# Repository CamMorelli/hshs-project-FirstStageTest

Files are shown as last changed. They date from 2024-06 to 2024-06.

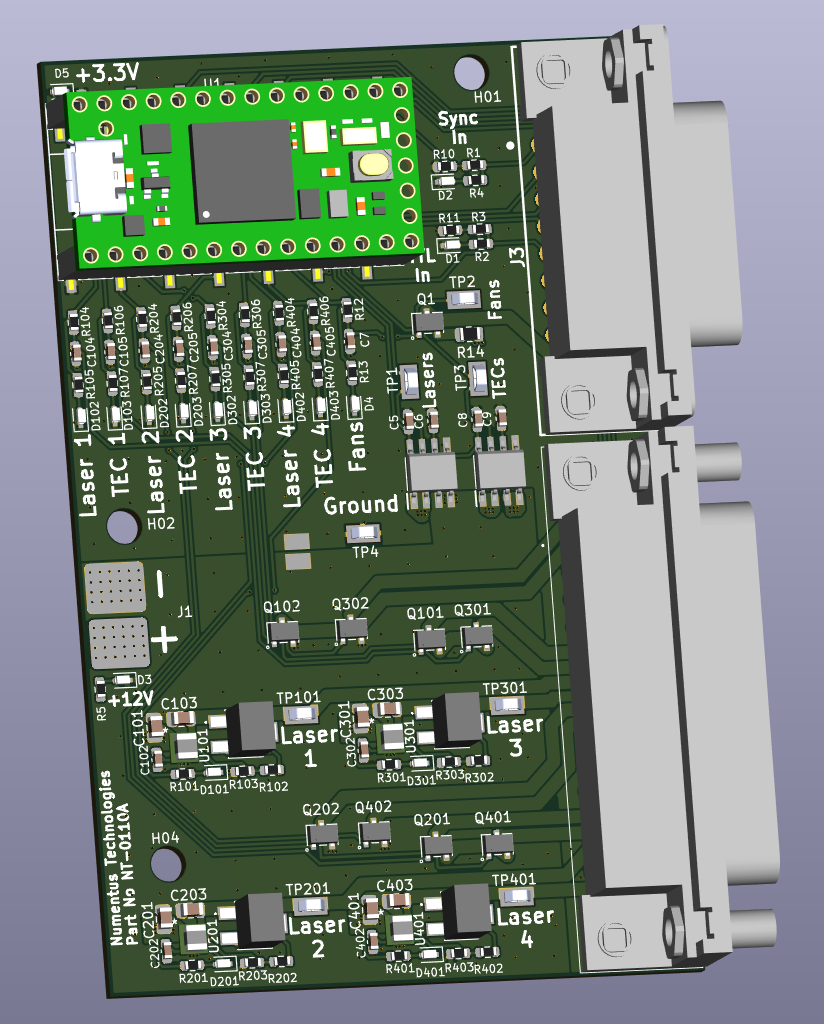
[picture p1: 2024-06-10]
Hardware/HSHS Interface Board 0110B/Assembly Documents/Screen Shot 2024-04-10 at 11.27.20 AM.png

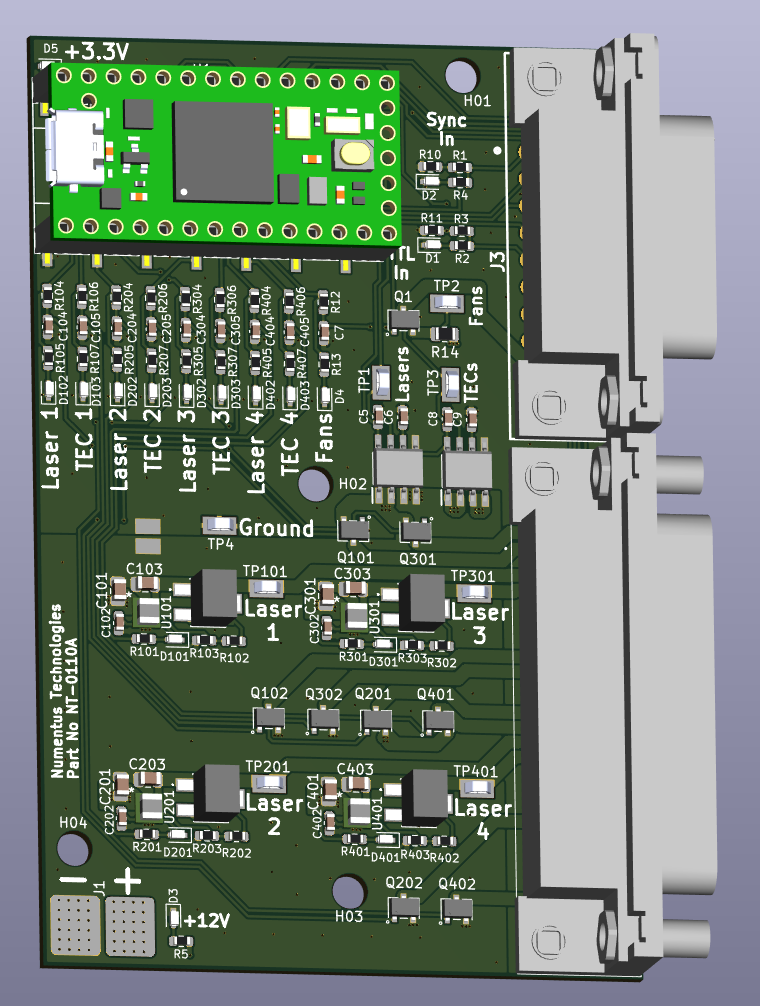
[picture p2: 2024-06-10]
Hardware/HSHS Interface Board 0110A/Assembly Documents/Screen Shot 2024-03-24 at 6.15.04 PM.png

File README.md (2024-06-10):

# crisp teensy project

## Getting started

To make it easy for you to get started with GitLab, here's a list of recommended next steps.

Already a pro? Just edit this README.md and make it your own. Want to make it easy? [Use the template at the bottom](#editing-this-readme)!

## Add your files

- [ ] [Create](https://docs.gitlab.com/ee/user/project/repository/web_editor.html#create-a-file) or [upload](https://docs.gitlab.com/ee/user/project/repository/web_editor.html#upload-a-file) files
- [ ] [Add files using the command line](https://docs.gitlab.com/ee/gitlab-basics/add-file.html#add-a-file-using-the-command-line) or push an existing Git repository with the following command:

```
cd existing_repo
git remote add origin https://gitlab.com/numentus-technologies/crisp-teensy-project.git
git branch -M main
git push -uf origin main
```

## Integrate with your tools

- [ ] [Set up project integrations](https://gitlab.com/numentus-technologies/crisp-teensy-project/-/settings/integrations)

## Collaborate with your team

- [ ] [Invite team members and collaborators](https://docs.gitlab.com/ee/user/project/members/)
- [ ] [Create a new merge request](https://docs.gitlab.com/ee/user/project/merge_requests/creating_merge_requests.html)
- [ ] [Automatically close issues from merge requests](https://docs.gitlab.com/ee/user/project/issues/managing_issues.html#closing-issues-automatically)
- [ ] [Enable merge request approvals](https://docs.gitlab.com/ee/user/project/merge_requests/approvals/)
- [ ] [Set auto-merge](https://docs.gitlab.com/ee/user/project/merge_requests/merge_when_pipeline_succeeds.html)

## Test and Deploy

Use the built-in continuous integration in GitLab.

- [ ] [Get started with GitLab CI/CD](https://docs.gitlab.com/ee/ci/quick_start/index.html)
- [ ] [Analyze your code for known vulnerabilities with Static Application Security Testing(SAST)](https://docs.gitlab.com/ee/user/application_security/sast/)
- [ ] [Deploy to Kubernetes, Amazon EC2, or Amazon ECS using Auto Deploy](https://docs.gitlab.com/ee/topics/autodevops/requirements.html)
- [ ] [Use pull-based deployments for improved Kubernetes management](https://docs.gitlab.com/ee/user/clusters/agent/)
- [ ] [Set up protected environments](https://docs.gitlab.com/ee/ci/environments/protected_environments.html)

***

# Editing this README

When you're ready to make this README your own, just edit this file and use the handy template below (or feel free to structure it however you want - this is just a starting point!). Thank you to [makeareadme.com](https://www.makeareadme.com/) for this template.

## Suggestions for a good README
Every project is different, so consider which of these sections apply to yours. The sections used in the template are suggestions for most open source projects. Also keep in mind that while a README can be too long and detailed, too long is better than too short. If you think your README is too long, consider utilizing another form of documentation rather than cutting out information.

## Name
Teensy interface for ASI Imaging CRISP autofocus module

## Description
Let people know what your project can do specifically. Provide context and add a link to any reference visitors might be unfamiliar with. A list of Features or a Background subsection can also be added here. If there are alternatives to your project, this is a good place to list differentiating factors.

## Badges
On some READMEs, you may see small images that convey metadata, such as whether or not all the tests are passing for the project. You can use Shields to add some to your README. Many services also have instructions for adding a badge.

## Visuals
Depending on what you are making, it can be a good idea to include screenshots or even a video (you'll frequently see GIFs rather than actual videos). Tools like ttygif can help, but check out Asciinema for a more sophisticated method.

## Installation
Within a particular ecosystem, there may be a common way of installing things, such as using Yarn, NuGet, or Homebrew. However, consider the possibility that whoever is reading your README is a novice and would like more guidance. Listing specific steps helps remove ambiguity and gets people to using your project as quickly as possible. If it only runs in a specific context like a particular programming language version or operating system or has dependencies that have to be installed manually, also add a Requirements subsection.

## Usage
Use examples liberally, and show the expected output if you can. It's helpful to have inline the smallest example of usage that you can demonstrate, while providing links to more sophisticated examples if they are too long to reasonably include in the README.

## Support
Tell people where they can go to for help. It can be any combination of an issue tracker, a chat room, an email address, etc.

## Roadmap
If you have ideas for releases in the future, it is a good idea to list them in the README.

## Contributing
State if you are open to contributions and what your requirements are for accepting them.

For people who want to make changes to your project, it's helpful to have some documentation on how to get started. Perhaps there is a script that they should run or some environment variables that they need to set. Make these steps explicit. These instructions could also be useful to your future self.

You can also document commands to lint the code or run tests. These steps help to ensure high code quality and reduce the likelihood that the changes inadvertently break something. Having instructions for running tests is especially helpful if it requires external setup, such as starting a Selenium server for testing in a browser.

## Authors and acknowledgment
Show your appreciation to those who have contributed to the project.

## License
For open source projects, say how it is licensed.

## Project status
If you have run out of energy or time for your project, put a note at the top of the README saying that development has slowed down or stopped completely. Someone may choose to fork your project or volunteer to step in as a maintainer or owner, allowing your project to keep going. You can also make an explicit request for maintainers.

# Cameron: These are my personal setups for VS Code and C++ thus far for documentation purposes.

# For the setup of VS Code, so far I have installed the following extensions:
Python
C/C++
C/C++ Extension Pack
C/C++ Themes
CMake
Cmake Tools
Doxygen Documentation Generator
Git Graph
GitLab Workflow
PlatformIO IDE
Pylance
Pylint
Python Debugger

# I then installed the following modules via pip using the command "pip install (module)":
numpy
matplotlib
pyserial **NOTE: for the import command to access pyserial, the command is as follows: "import serial" NOT "import pyserial"**

# For the setup of GitLab and GitHub, I signed into my Git account, and linked it to VS Code through the GitLab Workflow extension.
This allowed me to save my changes as my account and properly document it under GitGraph when a change is requested.
I then accessed the specific online (not local) repository via email granted access from the authorized user.
I continue to access the HSHS project via GitLab's website. (To first log in there will be a free trial button, of which, if you press, will being you to a sign in button in order to access your preexisting account)

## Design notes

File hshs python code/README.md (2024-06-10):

# Teensy CRISP python

## Name
Teensy CRISP python

## Known Bugs

## Testing
Tested on Python 3.10

## Description
<!-- Let people know what your project can do specifically. Provide context and add a link to any reference visitors might be unfamiliar with. A list of Features or a Background subsection can also be added here. If there are alternatives to your project, this is a good place to list differentiating factors. -->

Handling widget events:
The program responds to both shortcut keys and clicking widgets. The supporting code is primarily in hshs_gui_interface
Shortcut keys (in key_list) are bound to the function handle_global_key_press, which then calls functions by key
Clicking widgets results in function calls, set up during creation using "command = "
<KeyRelease> is bound to function handle_entry_key_press as follows:
For 'Up' and 'Down' arrows, current value (text) is tested for validity for arrow changes, then increamented/decremented based on cursor position
'Return' or 'KP_Enter' call focus to the main controller (focus out for the widget); tab also generates a focus out withut this step
<FocusOut> is bound to handle_focus_out, which also updates widgets and calls functions
Both 'Up' and 'Down' (handle_entry_key_press, but no FocusOut) and <FocusOut> update widgets through:
(1) update_param method for EntryParam Class: does validity check, then updates stored variable and widget display
(2) calls to update_plot_limits (axis values) or update_mcu (microcontroller values) to make changes 

To add to GUI:
    Add frame for GUI elements in pcr_controller_new_start in Class init for proper page (Settings, Data, or Fits)
    create method to populate widgets (e.g., roi_centers_controls_widgets, pwm_controls_widgets
    Call method from main program (pcr_controller_new_start)
    Define value, default value, max, min, etc for each widget
    Each element will reference the frame from first step
    Include list of widgets for (1) inclusion of current values in config.json file and (2) loop creation such as by gui_obj.create_widgets or gui_obj.create_buttons
    Add above list to json_obj_list

To add states:
    Edit state_control.hpp and hshs_constants.py to add new state to stateType and STATE_LIST and PLOT_TYPE, respectively
    Add state button in self.button_type in mcu_comm, and 
    Add state shortcut to key_list in hshs_controller and handle_mcu_command in mcu_comm
    Edit serial_comm.cpp to add relevant commands to help list and command call to processInputLine
    Edit process.hpp and process.cpp to add function to handle command
    Edit state_control.hpp to handle appropriate case(s) in updateState

## Files
hshs_controller_new-start.py: Starts up program, handling the creation and eventual destruction of Tkinter GUI
hshs_mcu_comm.py: Handles reading and writing from port (read from port thread) as well as interaction between user and GUI
hshs_plot_class.py: Handles details of displaying images and other data on GUI
hshs_gui_interface.py: Basic functionality of interacting with GUI like creating buttons and handling key presses
hshs_file_save.py: Handle file save thread, saving data to files
hshs_constants.py: Center for constants to be used in dimenions of GUI

## Visuals
<!-- Depending on what you are making, it can be a good idea to include screenshots or even a video (you'll frequently see GIFs rather than actual videos). Tools like ttygif can help, but check out Asciinema for a more sophisticated method. -->

## Installation

You will need to install several modules (e.g. using pip) including: serial, pyserial

<!-- Within a particular ecosystem, there may be a common way of installing things, such as using Yarn, NuGet, or Homebrew. However, consider the possibility that whoever is reading your README is a novice and would like more guidance. Listing specific steps helps remove ambiguity and gets people to using your project as quickly as possible. If it only runs in a specific context like a particular programming language version or operating system or has dependencies that have to be installed manually, also add a Requirements subsection. -->

## Usage
<!-- Use examples liberally, and show the expected output if you can. It's helpful to have inline the smallest example of usage that you can demonstrate, while providing links to more sophisticated examples if they are too long to reasonably include in the README. -->

## Support
<!-- Tell people where they can go to for help. It can be any combination of an issue tracker, a chat room, an email address, etc. -->

## Roadmap
<!-- Ideas for the future. -->

Update command list, implement/repurpose commands, implement/repurpose return values

States: Lock, ready (no servo), manual servo, scan, off (LED off)

Commands: Lock, Ready, Manual, scan (limits, time), servo level (value), LED level (value), servo off, gain values
Error - servo at limit
Limit servo rate of change
Add PID/Lock

Outputs to MCU: state changes, live servo voltage, LED level
Returns from MCU: two photodiode signals, error signal, servo voltage, state

Consider what warnings/confirmations you want to pop up when the user tries to do something that is unavailable or risky.

Add an option for pausing collection.

To get more control over the placement of elements on the Data Page, one might consider breaking up the display frame into more rows and columns and just increasing the span of those large elements that are currently there.

Some reorganization across classes and files could make the code more digestible. pcr_mcu_comm.py is especially long
## Contributing
<!-- State if you are open to contributions and what your requirements are for accepting them.

For people who want to make changes to your project, it's helpful to have some documentation on how to get started. Perhaps there is a script that they should run or some environment variables that they need to set. Make these steps explicit. These instructions could also be useful to your future self.

You can also document commands to lint the code or run tests. These steps help to ensure high code quality and reduce the likelihood that the changes inadvertently break something. Having instructions for running tests is especially helpful if it requires external setup, such as starting a Selenium server for testing in a browser. -->

## Authors and acknowledgment
Gregory Faris

## License
<!-- For open source projects, say how it is licensed. -->

## Project status
<!-- If you have run out of energy or time for your project, put a note at the top of the README saying that development has slowed down or stopped completely. Someone may choose to fork your project or volunteer to step in as a maintainer or owner, allowing your project to keep going. You can also make an explicit request for maintainers. -->

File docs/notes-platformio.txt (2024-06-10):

(1) teensy
https://www.pjrc.com/store/teensy40.html#photos

download teensy loader on ubuntu and mac
https://www.pjrc.com/teensy/loader_linux.html
success

executed ./teensy
success

screen /dev/ttyACM0 115200  (linux)
screen /dev/ttyACM0 115200  (linux)

control-c / control-d
success

platformio tutorial
https://www.youtube.com/watch?v=k3tpNwXEWhU

platformio useful commands:
View/Command Palette -> PlatformIO: Rebuild Intellisense Index

platformio docs home:
https://docs.platformio.org/en/latest/core/index.html

cd teensy-a(b)
PATH=${PATH}:${HOME}/.platformio/penv/bin

pio lib search "id:89"
pio lib search "platform: Espressif 8266 AND keyword:mqtt"
pio lib search "platform: Espressif 8266 AND keyword:serial"
pio lib search "id:89 8266 AND keyword:mqtt"
pio lib search -n mqtt
pio settings get

There is no equivalent icon in VSCode for this command. If you want to do this in VSCode, click on "pio" folder from right side in Teensy A or teensy
B and then selecting delete
rm -rf .pio 

This is the same as the trash can
pio run --target clean

This is the same as the check icon
pio run -v

This is the same as the right arrow icon
pio run --target upload

This is the same as the power plug
pio device monitor

NOTE: WHEN IN TROUBLE and there are issues with common library (i.e., with  LineParsingResult, getToken, etc)  
or when editing lib from IDE and "trash can" doesn't clear prior pio build,
try right clicking ".pio" folder from right side in Teensy A or teensy
B and then selecting delete. This is OK and doesn't hurt anything as .pio will be restored during the next build

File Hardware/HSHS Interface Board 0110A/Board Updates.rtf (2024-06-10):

Board Updates
Add ground test point
Move Laser and TEC LED Indicators to outputs somehow???
Less current to indicator LEDs (more than 500 Ohms) (balance lumens?)
Use Hall sensors for current
Power supply to outside
Mounting holes
Update LED footprints (AA1608SYSK?)
Rationalize LED numbering better
Gate discharge resistor and capacitor to ground

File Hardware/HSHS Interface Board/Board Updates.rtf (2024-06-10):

Board Updates
Mounting holes disappearing - add to schematic?
Better rationalize LED numbering
Redo fab documents
Read Hall sensor data sheet
New parts: 30nF caps, new DE-15, Hall sensor - S - suffix, solder paste, wire wrap recepticles
Add ground vias, adjust ground via positions

FIX POLARITY ON LASER/TEC
Add ground test point and test points for current monitors
Move Laser and TEC LED Indicators to outputs somehow???
Less current to indicator LEDs (more than 500 Ohms) (balance lumens?)
Use Hall sensors for current
Power supply to outside
Mounting holes
Update LED footprints (AA1608SYSK?)
Gate discharge resistor and capacitor to MCU ground?
Remove unneeded gate resistor (indicator LED does the job)
Remove test point, 0.1 and 10 resistors on MOSFET outputs; only use test points on Hall sensor output?
Change DA-15 connector?
Inspect 5788798-1 footprint - no ground lug
D sub connector outlines
Shrink net tie
Spacing for screw heads
Reduce text for Capacitor_SMD:C_0603_1608Metric, AA1608 Generic Kingbrite LED, Resistor_SMD:C_0603_1608Metric

Test red laser to see if damaged

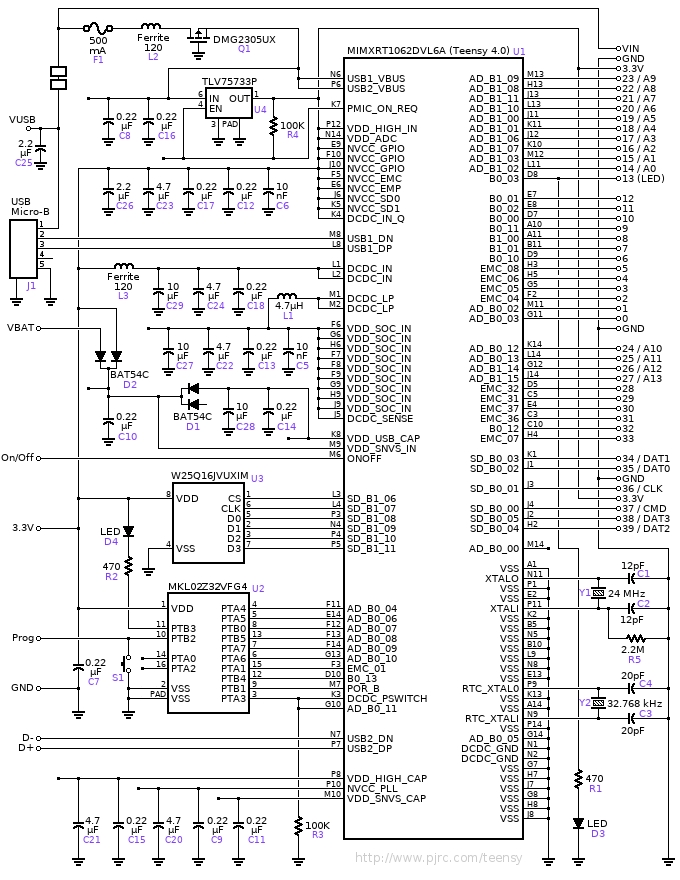
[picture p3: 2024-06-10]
docs/teensy-4.0/schematic40.png

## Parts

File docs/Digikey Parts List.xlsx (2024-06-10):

Ref | Index | Quantity | Part Number | Manufacturer Part Number | Description | Customer Reference | Available | Backorder | Unit Price | Extended Price USD
C01 | 17 | 50 | 1276-1102-1-ND | CL10A105KA8NNNC | CAP CER 1UF 25V X5R 0603 |  | 50 | 0 | 0.017 | 0.85
C06 | 18 | 100 | 399-C0603C103K3RAC7867CT-ND | C0603C103K3RAC7867 | CAP CER 10000PF 25V X7R 0603 |  | 100 | 0 | 0.0263 | 2.63
C08 | 24 | 10 | 1276-1096-1-ND | CL21A106KOQNNNE | CAP CER 10UF 16V X5R 0805 |  | 10 | 0 | 0.07 | 0.70
C12 | 7 | 10 | 445-14560-1-ND | C2012X7S1A226M125AC | CAP CER 22UF 10V X7S 0805 |  | 10 | 0 | 0.462 | 4.62
D1 | 8 | 20 | 754-AA1608ZGSK-10MAVCT-ND | AA1608ZGSK-10MAV | LED GREEN CLEAR 0603 SMD |  | 20 | 0 | 0.332 | 6.64
D5 | 9 | 20 | 754-AA1608QBS/D-10MAVCT-ND | AA1608QBS/D-10MAV | LED BLUE CLEAR 0603 SMD |  | 20 | 0 | 0.315 | 6.30
D6 | 10 | 20 | 754-AA1608SYSKCT-ND | AA1608SYSK | LED YELLOW CLEAR 0603 SMD |  | 20 | 0 | 0.315 | 6.30
D8 | 11 | 20 | 754-AA1608SURSKCT-ND | AA1608SURSK | LED RED CLEAR 0603 SMD |  | 20 | 0 | 0.315 | 6.30
J1
J2 | 12 | 3 | A132515-ND | 2301845-2 | CONN D-SUB RCPT 15POS R/A SLDR |  | 3 | 0 | 4.91 | 14.73
J3 | 13 | 3 | A35139-ND | 5788801-1 | CONN D-SUB RCPT 25POS R/A SLDR |  | 3 | 0 | 8.04 | 24.12
J4
Q1 | 2 | 24 | SSM3K376RLFCT-ND | SSM3K376R,LF | MOSFET N-CH 30V 4A SOT23F |  | 24 | 0 | 0.289 | 6.94
R01 | 19 | 50 | 13-RC0603FR-10499RLCT-ND | RC0603FR-10499RL | RES 499 OHM 1% 1/10W 0603 |  | 50 | 0 | 0.0112 | 0.56
R02 | 22 | 50 | 311-1.00KHRCT-ND | RC0603FR-071KL | RES 1K OHM 1% 1/10W 0603 |  | 50 | 0 | 0.0112 | 0.56
R04 | 20 | 100 | RMCF0603FT10K0CT-ND | RMCF0603FT10K0 | RES 10K OHM 1% 1/10W 0603 |  | 100 | 0 | 0.0075 | 0.75
R16 | 24 | 50 | RL12S.10FCT-ND | RL1220S-R10-F | RES 0.1 OHM 1% 1/3W 0805 |  | 50 | 0 | 0.1318 | 6.59
R25 | 21 | 100 | 311-15.0KHRCT-ND | RC0603FR-0715KL | RES 15K OHM 1% 1/10W 0603 |  | 100 | 0 | 0.0093 | 0.93
R28 | 23 | 50 | P24.9KHCT-ND | ERJ-3EKF2492V | RES SMD 24.9K OHM 1% 1/10W 0603 |  | 50 | 0 | 0.0194 | 0.97
TP1 | 14 | 40 | 36-5015CT-ND | 5015 | PC TEST POINT MINIATURE |  | 40 | 0 | 0.3684 | 14.74
U1 | 15 | 2 | 1568-DEV-16997-ND | DEV-16997 | TEENSY 4.0 (HEADERS) |  | 2 | 0 | 28.5 | 57.00
U2 | 1 | 12 | 296-TPSM82902SISRCT-ND | TPSM82902SISR | 3-V TO 17-V, 2-A HIGH EFFICIENCY |  | 12 | 0 | 3.678 | 44.14
VR1 | 16 | 15 | SM-42TX104CT-ND | SM-42TX104 | TRIMMER 100K OHM 0.25W GW TOP |  | 15 | 0 | 3.874 | 58.11
Z1 | 4 | 1 | 1866-2119-ND | GST280A12-C6P | AC/DC DESKTOP ADAPTER 12V 252W |  | 1 | 0 | 100.49 | 100.49
Z1A | 5 | 5 | WM3802-ND | 0039281063 | CONN HEADER VERT 6POS 4.2MM |  | 5 | 0 | 1.19 | 5.95
Z2 | 3 | 6 | SAM1148-14-ND | SSM-114-L-SV | CONN RCPT 14POS 0.1 GOLD SMD |  | 6 | 0 | 4.18 | 25.08

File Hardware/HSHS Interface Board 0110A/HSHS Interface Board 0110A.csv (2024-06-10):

Reference | Value | Footprint | Datasheet | AVAILABILITY | Arrow Part Number | Arrow Price/Stock | DESCRIPTION | Datasheet_1 | Description | Digikey_Part_Number | Digikey_Price/Stock | Footprint_1 | Height | MF | MP | Manufacturer | Manufacturer Part Number | Manufacturer_Name | Manufacturer_Part_Number | Mouser Part Number | Mouser Price/Stock | PACKAGE | PRICE | PURCHASE-URL | Price Unit 1 | Value_1 | Vendor Web Page | Qty
C1-C4 | 1µF | Global_Footprint_Library:C_0603_1608Metric_Small_Font | ~ |  |  |  | CAP CER 1UF 25V X5R 0603 |  | CAP CER 1UF 25V X5R 0603 | 1276-1102-1-ND | https://www.digikey.com/en/products/detail/samsung-electro-mechanics/CL10A105KA8NNNC/3886760 |  |  |  |  |  | CL10A105KA8NNNC | Samsung Electro-Mechanics | CL10A105KA8NNNC |  |  |  | 0.017 |  | .1 |  |  | 4
C5, C8 | 0.1µF | Global_Footprint_Library:C_0603_1608Metric_Small_Font | https://datasheets.kyocera-avx.com/X7RDielectric.pdf |  |  |  |  |  | CAP CER 0.1UF 50V X7R 0603 | 478-10346-2-ND | https://www.digikey.com/en/products/detail/kyocera-avx/06035C104KAT4A/1600047 |  |  |  |  |  |  | KYOCERA AVX | 06035C104KAT4A |  |  |  |  |  |  |  |  | 2
C6, C9 | 33nF | Global_Footprint_Library:C_0603_1608Metric_Small_Font | https://media.digikey.com/pdf/Data%20Sheets/Samsung%20PDFs/CL10A105KA8NNNC_Spec.pdf |  |  |  |  |  | CAP CER 1UF 25V X5R 0603 | 1276-1102-2-ND | https://www.digikey.com/en/products/detail/samsung-electro-mechanics/CL10A105KA8NNNC/3886760 |  |  |  |  |  |  | Samsung Electro-Mechanics | CL10A105KA8NNNC |  |  |  |  |  | .1 |  |  | 2
C7, C102, C104, C105, C202, C204, C205, C302, C304, C305, C402, C404, C405 | 10nF | Global_Footprint_Library:C_0603_1608Metric_Small_Font | ~ |  |  |  | CAP CER 10000PF 25V X7R 0603 |  |  | 399-C0603C103K3RAC7867CT-ND |  |  |  |  |  |  | C0603C103K3RAC7867 |  |  |  |  |  | 0.0263 |  |  |  |  | 13
C101, C201, C301, C401 | 10µF | Capacitor_SMD:C_0805_2012Metric | ~ |  |  |  | CAP CER 10UF 16V X5R 0805 |  |  | 1276-1096-1-ND |  |  |  |  |  |  | CL21A106KOQNNNE |  |  |  |  |  | 0.07 |  |  |  |  | 4
C103, C203, C303, C403 | 22µF | Capacitor_SMD:C_0805_2012Metric | ~ |  |  |  | CAP CER 22UF 10V X7S 0805 |  |  | 445-14560-1-ND |  |  |  |  |  |  | C2012X7S1A226M125AC |  |  |  |  |  | 0.462 |  |  |  |  | 4
D1-D3, D5 | LED Green | Global_Footprint_Library:AA1608 Generic Kingbrite LED | https://www.kingbrightusa.com/images/catalog/SPEC/AA1608ZGSK-10MAV.pdf |  |  |  | LED GREEN CLEAR 0603 SMD |  | 1.6X0.8MM BLUE SMD LED | 754-AA1608ZGSK-10MAVCT-ND | https://www.digikey.com/en/products/detail/kingbright/AA1608QBS-D-10MAV/13997416 |  |  |  |  |  | AA1608ZGSK-10MAV | Kingbright | AA1608QBS/D-10MAV |  |  |  | 0.332 |  | 0.51 |  |  | 4
D4, D103, D203, D303, D403 | LED Blue | Global_Footprint_Library:AA1608 Generic Kingbrite LED | https://www.kingbrightusa.com/images/catalog/SPEC/AA1608QBS-D-10MAV.pdf |  |  |  | LED BLUE CLEAR 0603 SMD |  | 1.6X0.8MM BLUE SMD LED | 754-AA1608QBS/D-10MAVCT-ND | https://www.digikey.com/en/products/detail/kingbright/AA1608QBS-D-10MAV/13997416 |  |  |  |  |  | AA1608QBS/D-10MAV | Kingbright | AA1608QBS/D-10MAV |  |  |  | 0.315 |  | 0.51 |  |  | 5
D101, D201, D301, D401 | LED Red | Global_Footprint_Library:AA1608 Generic Kingbrite LED | https://www.kingbrightusa.com/images/catalog/SPEC/AA1608SURSK.pdf |  |  |  | LED RED CLEAR 0603 SMD |  | 1.6X0.8MM BLUE SMD LED | 754-AA1608SURSKCT-ND | https://www.digikey.com/en/products/detail/kingbright/AA1608QBS-D-10MAV/13997416 |  |  |  |  |  | AA1608SURSK | Kingbright | AA1608QBS/D-10MAV |  |  |  | 0.315 |  | 0.51 |  |  | 4
D102, D202, D302, D402 | LED Yellow | Global_Footprint_Library:AA1608 Generic Kingbrite LED | https://www.kingbrightusa.com/images/catalog/SPEC/AA1608SYSK.pdf |  |  |  | LED YELLOW CLEAR 0603 SMD |  | 1.6X0.8MM BLUE SMD LED | 754-AA1608SYSKCT-ND | https://www.digikey.com/en/products/detail/kingbright/AA1608QBS-D-10MAV/13997416 |  |  |  |  |  | AA1608SYSK | Kingbright | AA1608QBS/D-10MAV |  |  |  | 0.315 |  | 0.51 |  |  | 4
H1-H5 | MountingHole | MountingHole:MountingHole_3.5mm | ~ |  |  |  |  |  |  |  |  |  |  |  |  |  |  |  |  |  |  |  |  |  |  |  |  | 5
IC1, IC2 | ACS725LLCTR-10AU-T | Global_Footprint_Library:SOIC127P600X175-8N | https://www.allegromicro.com/~/media/Files/Datasheets/ACS725-Datasheet.ashx |  |  |  |  |  |  |  |  |  | 1.75 |  |  |  |  | Allegro Microsystems | ACS725LLCTR-10AU-T | 250-725LLCTR10AUT | https://www.mouser.co.uk/ProductDetail/Allegro-MicroSystems/ACS725LLCTR-10AU-T?qs=pUKx8fyJudDJhypXeBbXnA%3D%3D |  |  |  |  |  |  | 2
J1 | Conn_01x02_Pin | Global_Footprint_Library:Dual Solder Pads Both Sides No PTH | ~ |  |  |  |  |  |  |  |  |  |  |  |  |  |  |  |  |  |  |  |  |  |  |  |  | 1
J2 | 5788801-1 | Global_Footprint_Library:57888011_A | https://www.te.com/commerce/DocumentDelivery/DDEController?Action=showdoc |  | 5788801-1 | https://www.arrow.com/en/products/5788801-1/te-connectivity?region=nac | CONN D-SUB RCPT 25POS R/A SLDR |  |  | A35139-ND |  |  | 12.93 |  |  |  | 5788801-1 | TE Connectivity | 5788801-1 | 571-5788801-1 | https://www.mouser.co.uk/ProductDetail/TE-Connectivity-AMP/5788801-1?qs=PmjM%2FwY1RToSHOZP%252ByStZg%3D%3D |  | 8.04 |  |  |  |  | 1
J3 | 5788798-1 | Global_Footprint_Library:5788798-1 Fix_A | http://www.te.com/commerce/DocumentDelivery/DDEController?Action=showdoc |  |  |  |  |  |  |  |  |  |  |  |  |  |  | TE Connectivity | 5788798-1 | 571-5788798-1 | https://www.mouser.co.uk/ProductDetail/TE-Connectivity/5788798-1?qs=PmjM%2FwY1RTpVZANV1g1dAQ%3D%3D |  |  |  |  |  |  | 1
NT1 | NetTie_2 | Global_Footprint_Library:NetTieSolderBridgeSmaller | ~ |  |  |  |  |  |  |  |  |  |  |  |  |  |  |  |  |  |  |  |  |  |  |  |  | 1
Q1, Q101, Q102, Q201, Q202, Q301, Q302, Q401, Q402 | SSM3K376R_A | Global_Footprint_Library:SSM3K376R_Mod_A | https://toshiba.semicon-storage.com/info/SSM3K376R_datasheet_en_20210528.pdf?did=60463&prodName=SSM3K376R |  |  |  | MOSFET N-CH 30V 4A SOT23F | https://toshiba.semicon-storage.com/info/docget.jsp?did=60463&prodName=SSM3K376R | MOSFET N-CH 30V 4A SOT23F | SSM3K376RLFTR-ND | https://www.digikey.com/en/products/detail/toshiba-semiconductor-and-storage/SSM3K376R-LF/9472331 | SOTFL95P240X88-3N | .8 |  |  |  | SSM3K376R,LF | Toshiba Semiconductor and Storage | SSM3K376R,LF |  |  |  | 0.289 |  | .43 | SSM3K376R | https://toshiba.semicon-storage.com/us/semiconductor/product/mosfets/detail.SSM3K376R.html | 9
R1, R3, R13, R105, R107, R205, R207, R305, R307, R405, R407 | 500 | Global_Footprint_Library:R_0603_1608Metric_Small_Font | ~ |  |  |  | RES 499 OHM 1% 1/10W 0603 |  | -- mixed values -- | 13-RC0603FR-10499RLCT-ND | -- mixed values -- |  |  |  |  |  | RC0603FR-10499RL | -- mixed values -- | -- mixed values -- |  |  |  | 0.0112 |  | -- mixed values -- |  |  | 11
R2, R4, R10, R11, R15 | 1k | Global_Footprint_Library:R_0603_1608Metric_Small_Font | ~ |  |  |  | -- mixed values -- |  | -- mixed values -- | -- mixed values -- | -- mixed values -- |  |  |  |  |  | -- mixed values -- | -- mixed values -- | -- mixed values -- |  |  |  | 0.0112 |  | -- mixed values -- |  |  | 5
R5, R102, R202, R302, R402 | 25k | Global_Footprint_Library:R_0603_1608Metric_Small_Font | ~ |  |  |  | -- mixed values -- |  | -- mixed values -- | -- mixed values -- | -- mixed values -- |  |  |  |  |  | -- mixed values -- | -- mixed values -- | -- mixed values -- |  |  |  | -- mixed values -- |  | -- mixed values -- |  |  | 5
R6-R9, R12, R104, R106, R204, R206, R304, R306, R404, R406 | 10k | Global_Footprint_Library:R_0603_1608Metric_Small_Font | ~ |  |  |  | RES 10K OHM 1% 1/10W 0603 |  | -- mixed values -- | RMCF0603FT10K0CT-ND | -- mixed values -- |  |  |  |  |  | RMCF0603FT10K0 | -- mixed values -- | -- mixed values -- |  |  |  | 0.0075 |  | .1 |  |  | 13
R14 | 0.1 | Resistor_SMD:R_0805_2012Metric | ~ |  |  |  | RES 0.1 OHM 1% 1/3W 0805 |  |  | RL12S.10FCT-ND |  |  |  |  |  |  | RL1220S-R10-F |  |  |  |  |  | 0.1318 |  |  |  |  | 1
R101, R103, R201, R203, R301, R303, R401, R403 | 15k | Global_Footprint_Library:R_0603_1608Metric_Small_Font | ~ |  |  |  | RES 15K OHM 1% 1/10W 0603 |  | -- mixed values -- | 311-15.0KHRCT-ND | -- mixed values -- |  |  |  |  |  | RC0603FR-0715KL | -- mixed values -- | -- mixed values -- |  |  |  | 0.0093 |  | -- mixed values -- |  |  | 8
TP1-TP4, TP101, TP201, TP301, TP401 | 5015 | Global_Footprint_Library:KEYSTONE_5015 | https://www.keyelco.com/userAssets/file/M65p55.pdf | In Stock |  |  | SMT Test Point- Micro Miniature-1000 pc Reels |  |  | 36-5015CT-ND |  |  |  | Keystone Electronics | 5015 |  | 5015 | Keystone Electronics |  |  |  | None | 0.3684 | https://pricing.snapeda.com/search/part/5015/?ref=eda |  |  |  | 8
U1 | Teensy4.0_28_Pins | Global_Footprint_Library:Teensy40_with_3D_Model_28_Pins_Surface_Mount_C | https://cdn.sparkfun.com/assets/7/f/3/c/5/teensy40_pinout1.png |  |  |  | TEENSY 4.0 (HEADERS) |  |  | 1568-DEV-16997-ND |  |  |  |  |  |  | DEV-16997 | SparkFun Electronics |  |  |  |  | 28.5 |  |  |  |  | 1
U101, U201, U301, U401 | TPSM82902SISR | Global_Footprint_Library:uSIP11_SIS_TEX_Mod | https://www.ti.com/lit/ds/symlink/tpsm82902.pdf |  |  |  | 3-V TO 17-V, 2-A HIGH EFFICIENCY |  |  | 296-TPSM82902SISRCT-ND |  |  |  |  |  |  | TPSM82902SISR | Texas Instruments |  |  |  |  | 3.678 |  |  |  |  | 4
VR101, VR201, VR301, VR401 | SM-42X104 | Global_Footprint_Library:SM42X104_Smaller_Courtyard | https://www.nidec-copal-electronics.com/j/catalog/trimmer/sm-42&sm-43.pdf |  |  |  | TRIMMER 100K OHM 0.25W GW TOP |  |  | SM-42TX104CT-ND |  |  | 5.6 |  |  |  | SM-42TX104 | NIDEC COPAL | SM-42X104 | 229-SM-42X104 | https://www.mouser.co.uk/ProductDetail/Nidec-Copal/SM-42X104?qs=XeJtXLiO41RrA2qtCLniIg%3D%3D |  | 3.874 |  |  |  |  | 4

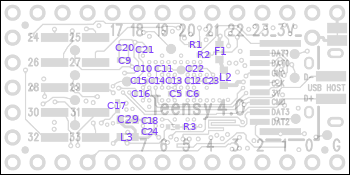
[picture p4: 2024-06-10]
docs/teensy-4.0/parts_placement_teensy40_bottom.png

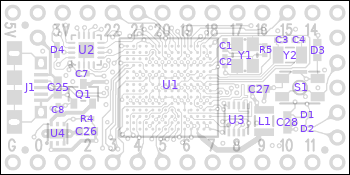
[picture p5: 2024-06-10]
docs/teensy-4.0/parts_placement_teensy40_top.png

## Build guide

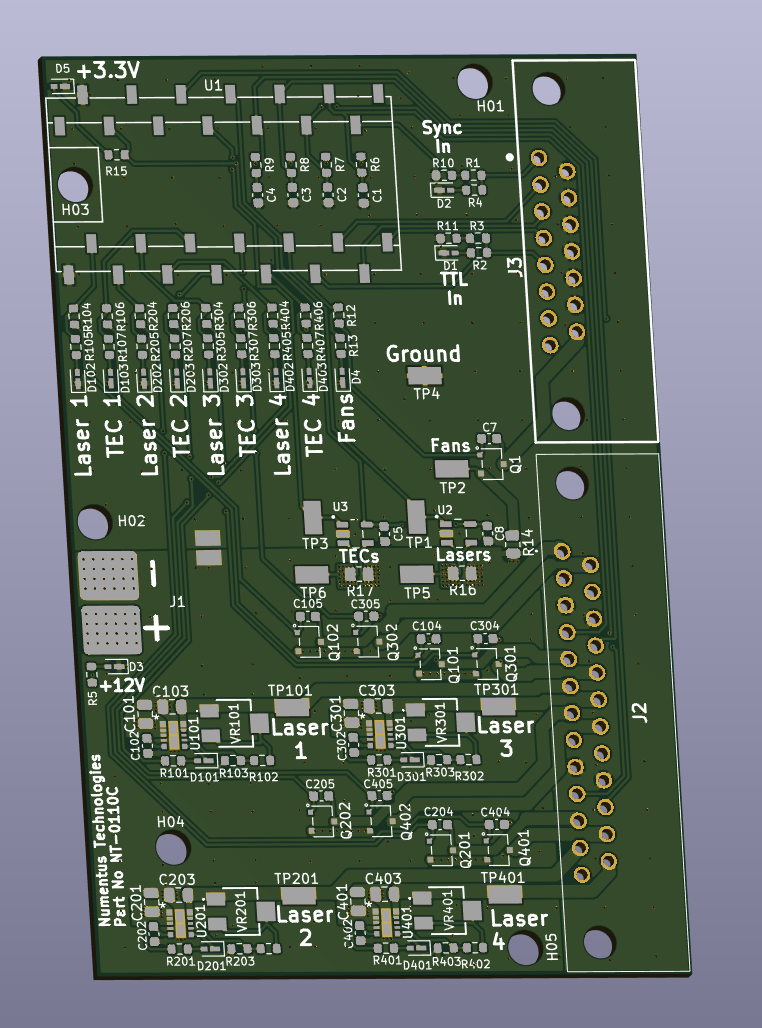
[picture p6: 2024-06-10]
Hardware/HSHS Interface Board 1010C/Assembly Documents/Screen Shot 2024-04-26 at 10.37.56 AM.png

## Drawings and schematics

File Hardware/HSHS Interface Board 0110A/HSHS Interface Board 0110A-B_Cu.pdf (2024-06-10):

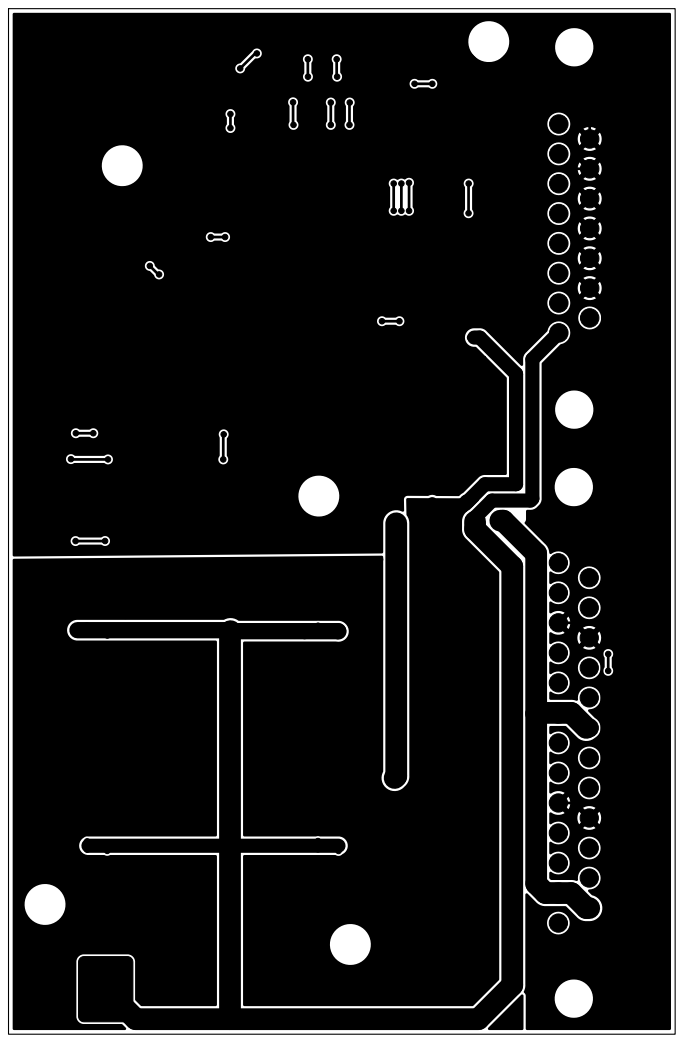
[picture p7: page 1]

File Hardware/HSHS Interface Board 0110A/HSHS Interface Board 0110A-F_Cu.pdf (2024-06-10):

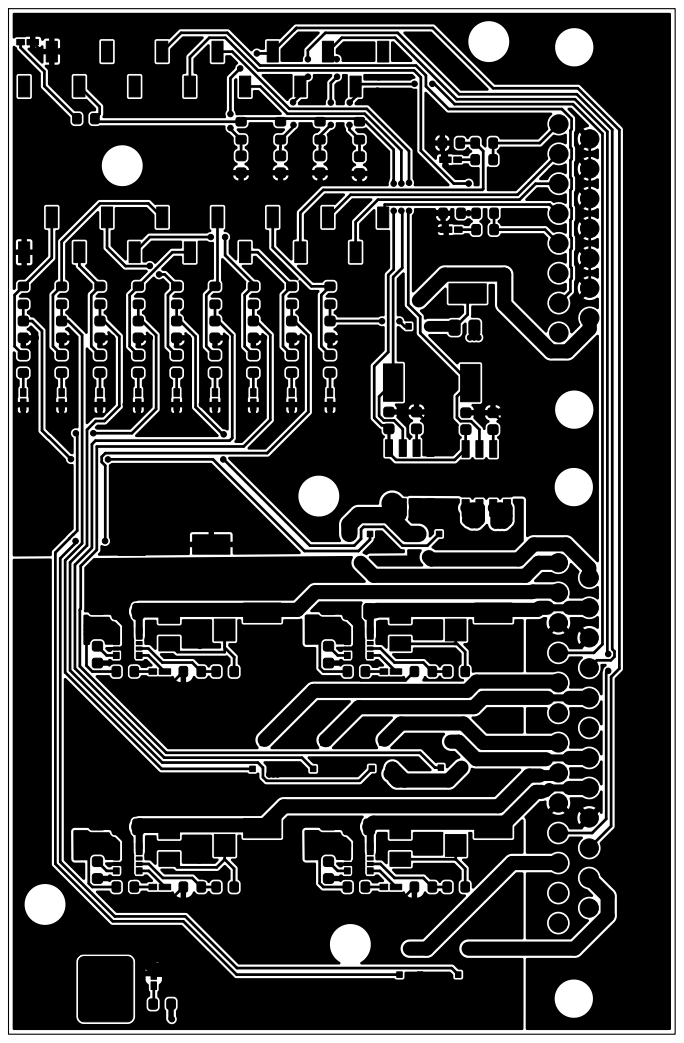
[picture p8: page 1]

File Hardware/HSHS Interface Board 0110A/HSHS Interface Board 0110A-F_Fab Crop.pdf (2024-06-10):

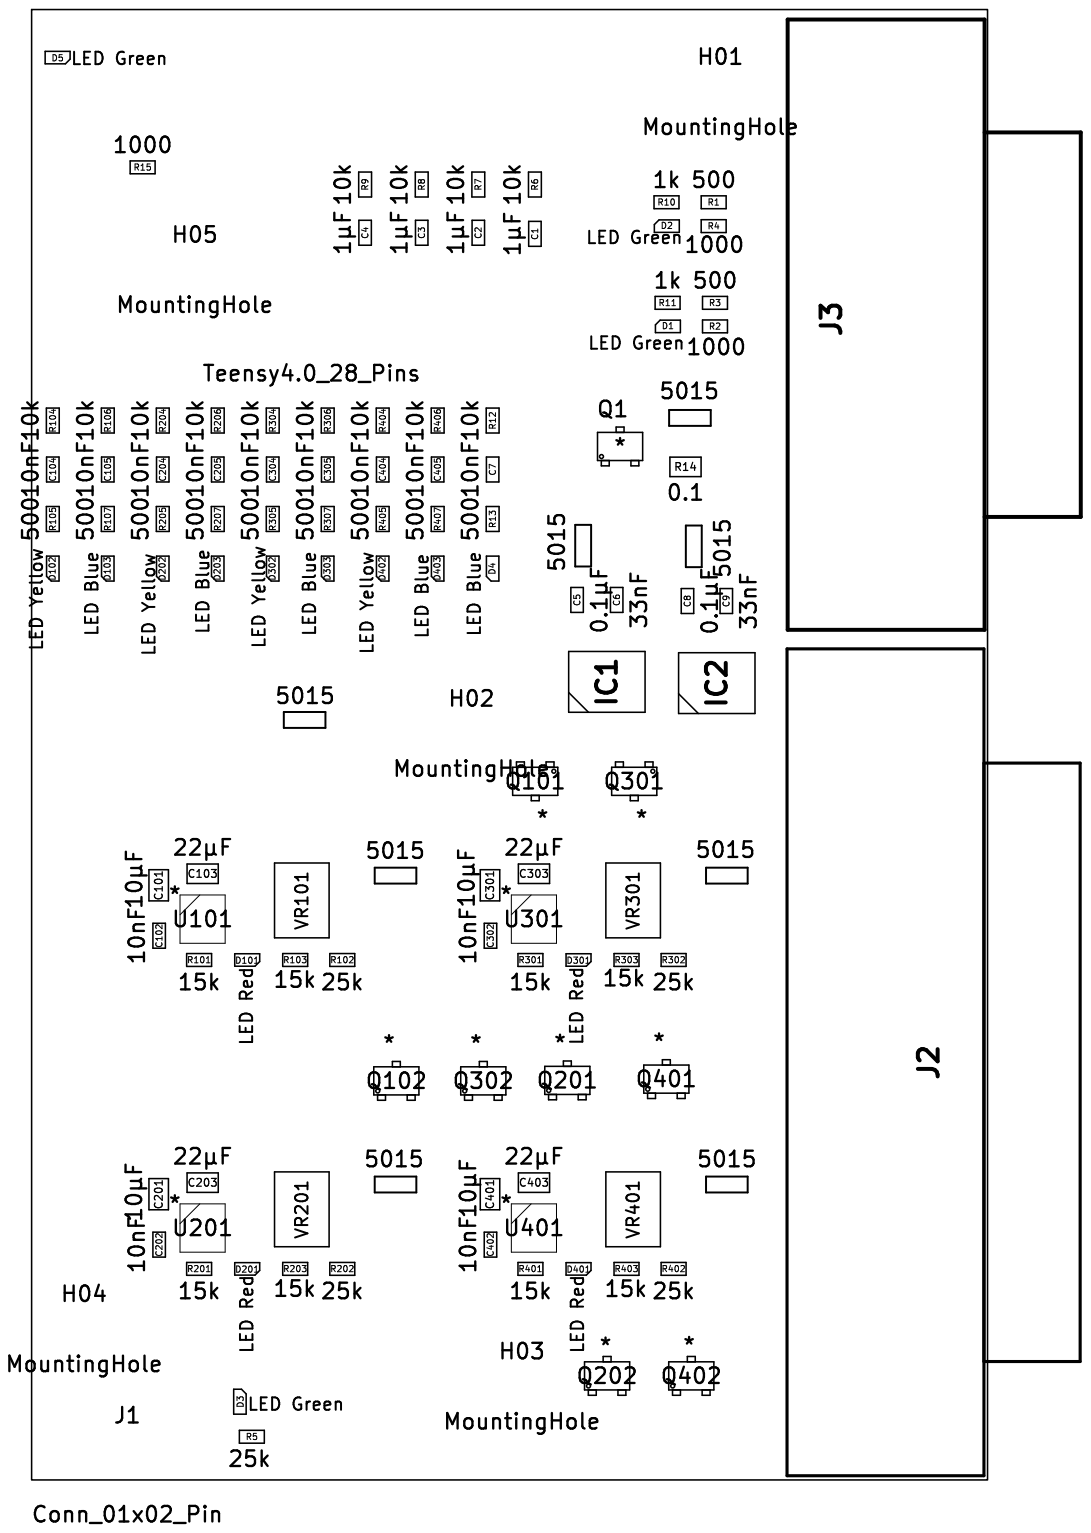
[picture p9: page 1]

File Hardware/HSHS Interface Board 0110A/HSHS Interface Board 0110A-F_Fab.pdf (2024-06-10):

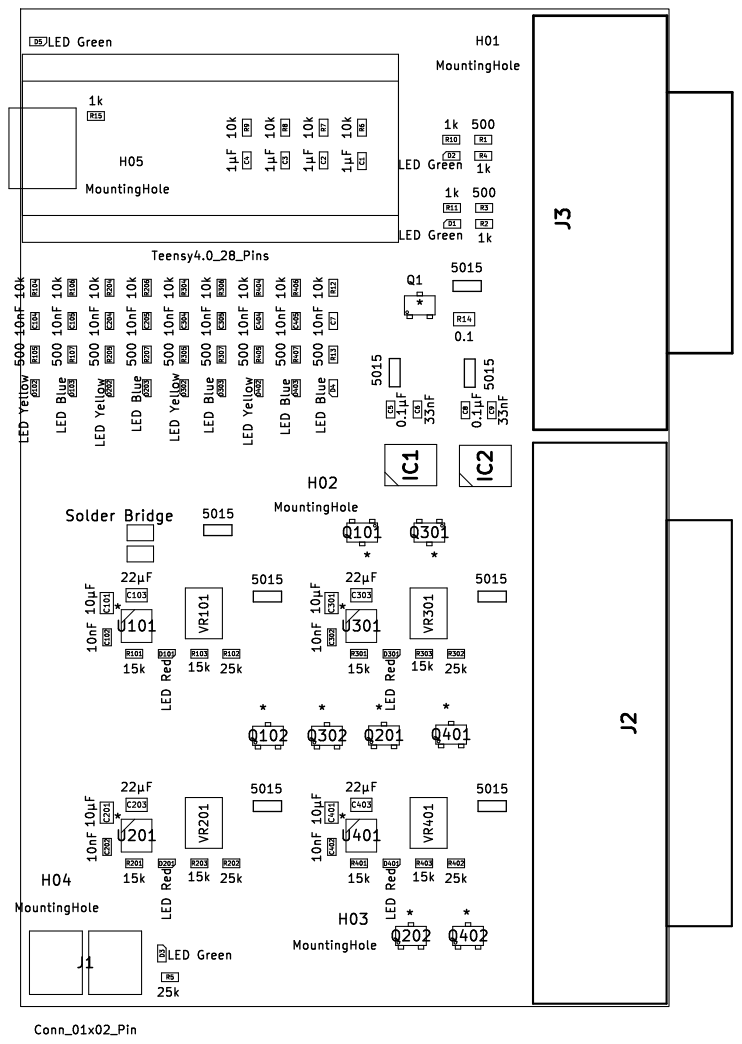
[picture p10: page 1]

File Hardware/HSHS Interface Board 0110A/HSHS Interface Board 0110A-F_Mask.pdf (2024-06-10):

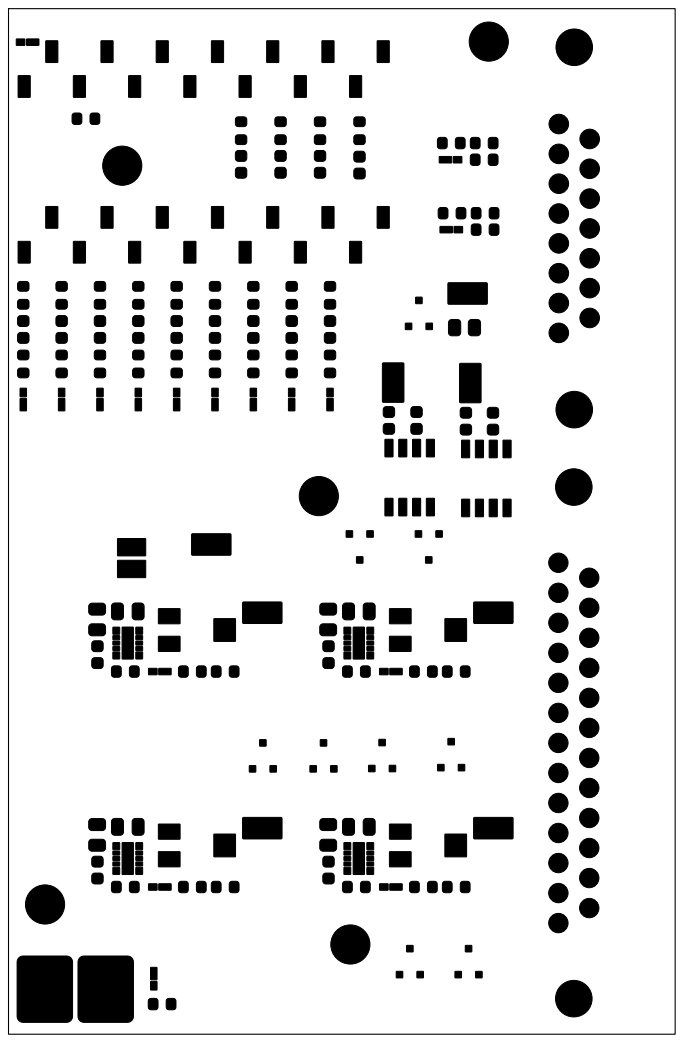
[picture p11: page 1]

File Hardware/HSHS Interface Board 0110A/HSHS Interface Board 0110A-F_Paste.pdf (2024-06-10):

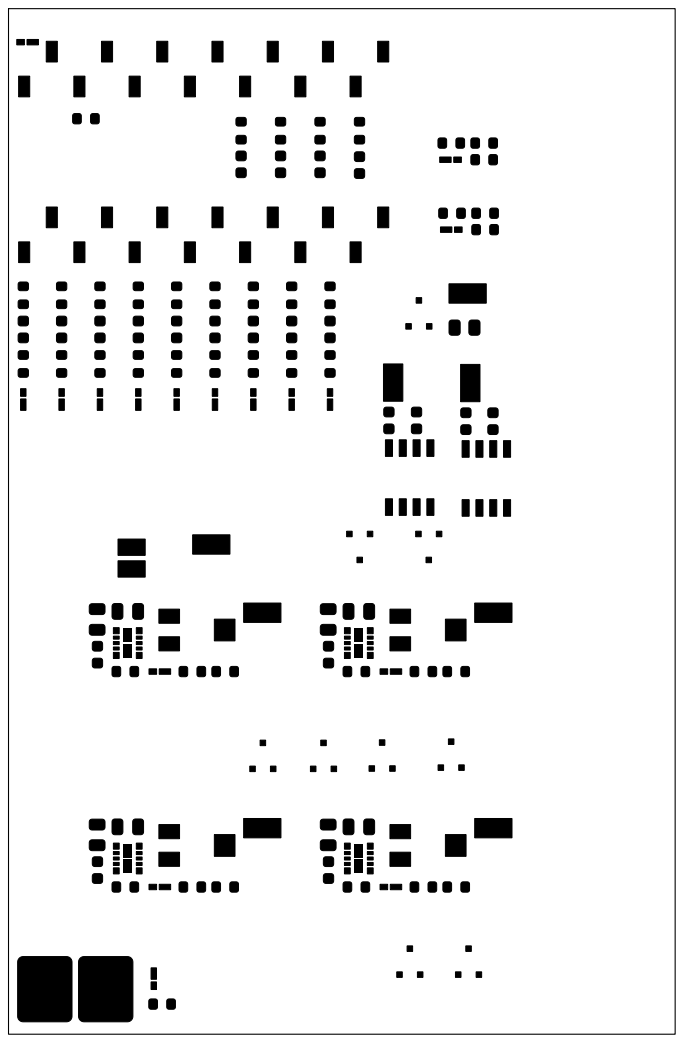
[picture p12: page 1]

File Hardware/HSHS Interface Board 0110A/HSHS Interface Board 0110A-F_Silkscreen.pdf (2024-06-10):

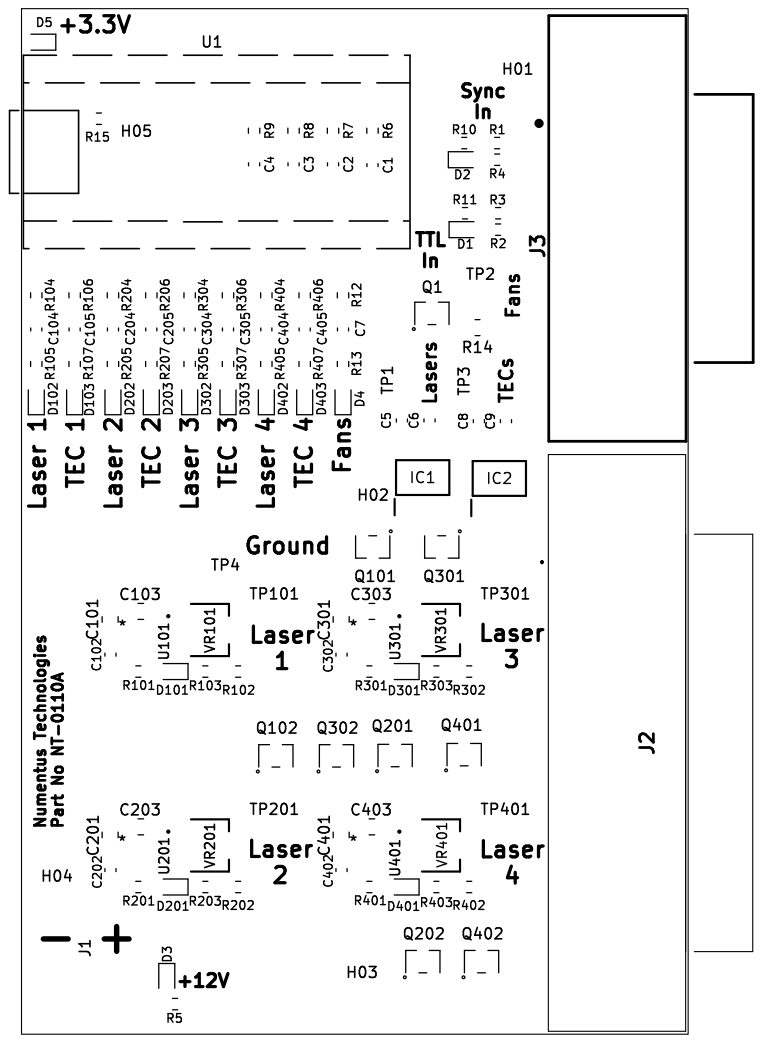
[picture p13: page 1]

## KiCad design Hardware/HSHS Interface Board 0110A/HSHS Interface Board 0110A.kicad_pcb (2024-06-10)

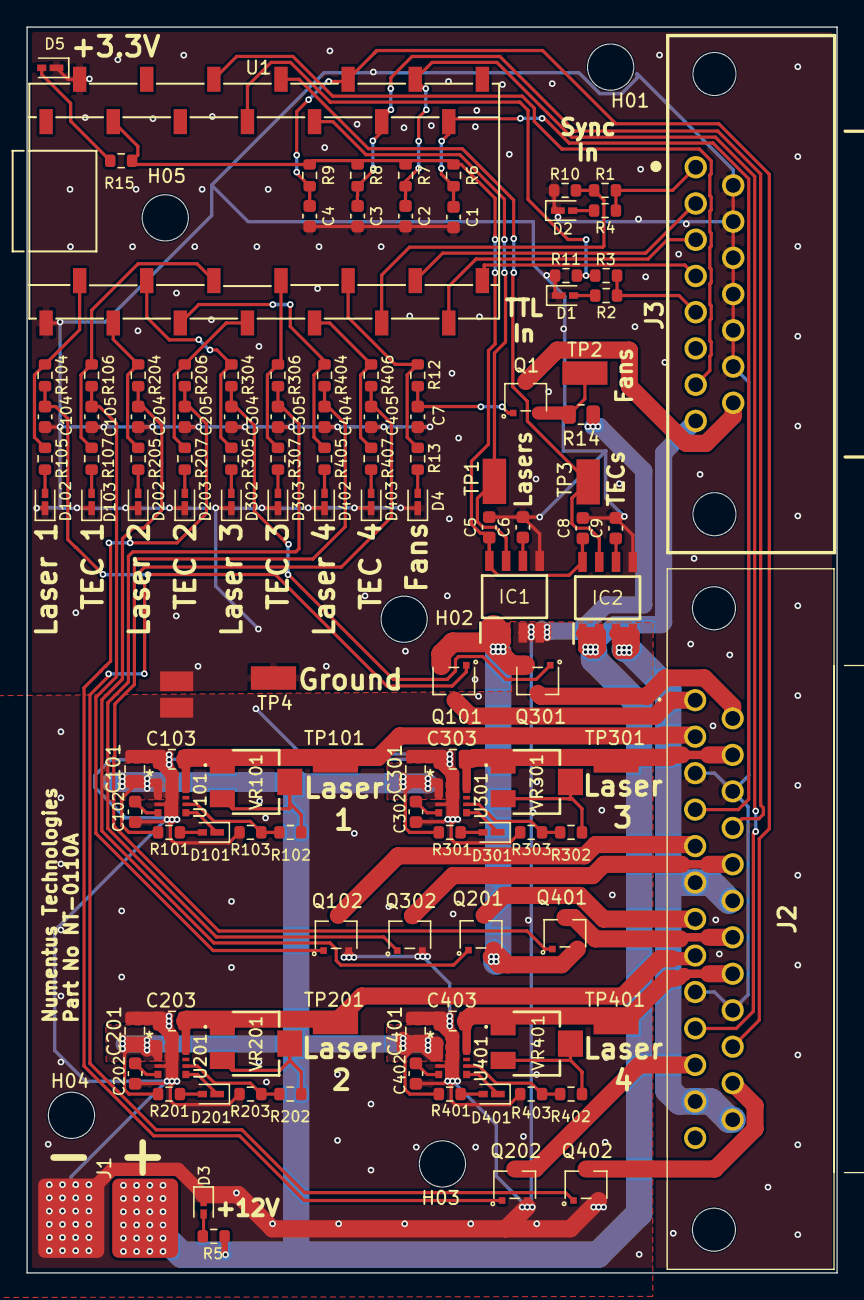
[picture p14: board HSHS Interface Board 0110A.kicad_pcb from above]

Board: 2 copper layers, 61.3 x 94.3 mm, 126 parts (0 on the bottom side), 87 nets.

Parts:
C1, C2, C3, C4: 1µF; C_0603_1608Metric_Small_Font
C5, C8: 0.1µF; C_0603_1608Metric_Small_Font
C6, C9: 33nF; C_0603_1608Metric_Small_Font
C7, C102, C104, C105, C202, C204, C205, C302, C304, C305, C402, C404, C405: 10nF; C_0603_1608Metric_Small_Font
C101, C201, C301, C401: 10µF; C_0805_2012Metric
C103, C203, C303, C403: 22µF; C_0805_2012Metric
D1, D2, D3, D5: LED Green; AA1608 Generic Kingbrite LED
D4, D103, D203, D303, D403: LED Blue; AA1608 Generic Kingbrite LED
D101, D201, D301, D401: LED Red; AA1608 Generic Kingbrite LED
D102, D202, D302, D402: LED Yellow; AA1608 Generic Kingbrite LED
H01, H02, H03, H04, H05: MountingHole; MountingHole_3.5mm
IC1, IC2: ACS725LLCTR-10AU-T; SOIC127P600X175-8N
J1: Conn_01x02_Pin; Dual Solder Pads Both Sides No PTH
J2: 5788801-1; 57888011_A
J3: 5788798-1; 5788798-1 Fix_A
NT1: Solder Bridge; NetTieSolderBridgeSmaller
Q1, Q101, Q102, Q201, Q202, Q301, Q302, Q401, Q402: SSM3K376R_A; SSM3K376R_Mod_A
R1, R3, R13, R105, R107, R205, R207, R305, R307, R405, R407: 500; R_0603_1608Metric_Small_Font
R2, R4, R10, R11, R15: 1k; R_0603_1608Metric_Small_Font
R5, R102, R202, R302, R402: 25k; R_0603_1608Metric_Small_Font
R6, R7, R8, R9, R12, R104, R106, R204, R206, R304, R306, R404, R406: 10k; R_0603_1608Metric_Small_Font
R14: 0.1; R_0805_2012Metric
R101, R103, R201, R203, R301, R303, R401, R403: 15k; R_0603_1608Metric_Small_Font
TP1, TP2, TP3, TP4, TP101, TP201, TP301, TP401: 5015; KEYSTONE_5015
U1: Teensy4.0_28_Pins; Teensy40_with_3D_Model_28_Pins_Surface_Mount_C
U101, U201, U301, U401: TPSM82902SISR; uSIP11_SIS_TEX_Mod
VR101, VR201, VR301, VR401: SM-42X104; SM42X104_Smaller_Courtyard

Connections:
+3.3V: C5.1, C8.1, IC1.8 (VCC), IC2.8 (VCC), R6.1, R7.1, R8.1, R9.1, R15.1, U1.3V3
+12V: C101.1, C201.1, C301.1, C401.1, IC2.1 (IP+_1), IC2.2 (IP+_2), J1.1, J3.8, R5.1, R101.1, R201.1, R301.1, R401.1, U101.1 (VIN), U101.2 (VIN), U101.3 (EN), U201.1 (VIN), U201.2 (VIN), U201.3 (EN), U301.1 (VIN), U301.2 (VIN), U301.3 (EN), U401.1 (VIN), U401.2 (VIN), U401.3 (EN)
/Camera A+: J3.2, U1.10 (10_CS_MQSR)
/Camera B+: J3.3, U1.11 (11_MOSI_CTX1)
/Camera C+: J3.4, U1.12 (12_MISO_MQSL)
/Clock3.3V+: R1.2, R10.1, U1.9 (9_OUT1C)
/Clock5V+: J3.1, R1.1, R4.1
/Fan-: J3.15, Q1.3 (D)
/FanControl: R12.1, R13.1, U1.8 (8_TX2_IN1)
/Laser Monitor: IC1.7 (VIOUT), TP1.TP, U1.18 (18_A4_SDA0)
/LaserControl1: R104.1, R105.1, U1.0 (0_RX1_CRX2_CS1)
/LaserControl2: R204.1, R205.1, U1.1 (1_TX1_CTX2_MISO1)
/LaserControl3: R304.1, R305.1, U1.2 (2_OUT2)
/LaserControl4: R404.1, R405.1, U1.3 (3_LRCLK2)
/LaserPow1+: C103.1, J2.2, TP101.TP, U101.9 (VOUT), U101.10 (VOUT), VR101.1 (CCW)
/LaserPow1-: J2.1, Q101.3 (D)
/LaserPow2+: C203.1, J2.8, TP201.TP, U201.9 (VOUT), U201.10 (VOUT), VR201.1 (CCW)
/LaserPow2-: J2.7, Q201.3 (D)
/LaserPow3+: C303.1, J2.15, TP301.TP, U301.9 (VOUT), U301.10 (VOUT), VR301.1 (CCW)
/LaserPow3-: J2.14, Q301.3 (D)
/LaserPow4+: C403.1, J2.21, TP401.TP, U401.9 (VOUT), U401.10 (VOUT), VR401.1 (CCW)
/LaserPow4-: J2.20, Q401.3 (D)
/Spare+: J3.7, U1.21 (21_A7_RX5_BCLK1)
/TEC High: IC2.3 (IP-_1), IC2.4 (IP-_2), J2.6, J2.12, J2.19, J2.25
/TEC Monitor: IC2.7 (VIOUT), TP3.TP, U1.19 (19_A5_SCL0)
/TECControl1: R106.1, R107.1, U1.4 (4_BCLK2)
/TECControl2: R206.1, R207.1, U1.5 (5_IN2)
/TECControl3: R306.1, R307.1, U1.6 (6_OUT1D)
/TECControl4: R406.1, R407.1, U1.7 (7_RX2_OUT1A)
/TECPow1-: J2.5, Q102.3 (D)
/TECPow2-: J2.11, Q202.3 (D)
/TECPow3-: J2.18, Q302.3 (D)
/TECPow4-: J2.24, Q402.3 (D)
/TTLOut3.3V+: R3.2, R11.1, U1.20 (20_A6_TX5_LRCLK1)
/TTLOut5V+: J3.5, R2.1, R3.1
/Therm1+: C1.1, J2.4, R6.2, U1.14 (14_A0_TX3_SPDIF_OUT)
/Therm2+: C2.1, J2.10, R7.2, U1.15 (15_A1_RX3_SPDIF_IN)
/Therm3+: C3.1, J2.17, R8.2, U1.16 (16_A2_RX4_SCL1)
/Therm4+: C4.1, J2.23, R9.2, U1.17 (17_A3_TX4_SDA1)
GNDA: C1.2, C2.2, C3.2, C4.2, C5.2, C6.2, C7.2, C8.2, C9.2, C104.2, C105.2, C204.2, C205.2, C304.2, C305.2, C404.2, C405.2, D1.1 (K), D2.1 (K), D4.1 (K), D5.1 (K), D102.1 (K), D103.1 (K), D202.1 (K), D203.1 (K), D302.1 (K), D303.1 (K), D402.1 (K), D403.1 (K), IC1.5 (GND), IC2.5 (GND), J2.3, J2.9, J2.16, J2.22, J3.9, J3.10, J3.11, J3.12, J3.13, J3.14, NT1.1, R10.2, R11.2, TP4.TP, U1.G1 (GND), U1.G2 (GND)
GNDPWR: C101.2, C102.2, C103.2, C201.2, C202.2, C203.2, C301.2, C302.2, C303.2, C401.2, C402.2, C403.2, D3.1 (K), IC1.3 (IP-_1), IC1.4 (IP-_2), J1.2, NT1.2, Q102.2 (S), Q202.2 (S), Q302.2 (S), Q402.2 (S), R14.2, R103.2, R203.2, R303.2, R403.2, U101.4 (MODE/S-CONF), U101.11 (GND), U201.4 (MODE/S-CONF), U201.11 (GND), U301.4 (MODE/S-CONF), U301.11 (GND), U401.4 (MODE/S-CONF), U401.11 (GND)
Laser MOSFET Low: IC1.1 (IP+_1), IC1.2 (IP+_2), Q101.2 (S), Q201.2 (S), Q301.2 (S), Q401.2 (S)
unnamed: D1.2 (A), R2.2
unnamed: D2.2 (A), R4.2
unnamed: D3.2 (A), R5.2
unnamed: D4.2 (A), R13.2
unnamed: D5.2 (A), R15.2
unnamed: D101.2 (A), R101.2
unnamed: D101.1 (K), U101.6 (PG)
unnamed: D102.2 (A), R105.2
unnamed: D103.2 (A), R107.2
unnamed: D201.2 (A), R201.2
unnamed: D201.1 (K), U201.6 (PG)
unnamed: D202.2 (A), R205.2
unnamed: D203.2 (A), R207.2
unnamed: D301.2 (A), R301.2
unnamed: D301.1 (K), U301.6 (PG)
unnamed: D302.2 (A), R305.2
unnamed: D303.2 (A), R307.2
unnamed: D401.2 (A), R401.2
unnamed: D401.1 (K), U401.6 (PG)
unnamed: D402.2 (A), R405.2
unnamed: D403.2 (A), R407.2
unnamed: C6.1, IC1.6 (FILTER)
unnamed: C9.1, IC2.6 (FILTER)
unnamed: C7.1, Q1.1 (G), R12.2
unnamed: Q1.2 (S), R14.1, TP2.TP
unnamed: C104.1, Q101.1 (G), R104.2
unnamed: C105.1, Q102.1 (G), R106.2
unnamed: C204.1, Q201.1 (G), R204.2
unnamed: C205.1, Q202.1 (G), R206.2
unnamed: C304.1, Q301.1 (G), R304.2
unnamed: C305.1, Q302.1 (G), R306.2
unnamed: C404.1, Q401.1 (G), R404.2
unnamed: C405.1, Q402.1 (G), R406.2
unnamed: R102.1, R103.1, U101.7 (FB/VSET)
unnamed: C102.1, U101.5 (SS/TR)
unnamed: R202.1, R203.1, U201.7 (FB/VSET)
unnamed: C202.1, U201.5 (SS/TR)
unnamed: R302.1, R303.1, U301.7 (FB/VSET)
unnamed: C302.1, U301.5 (SS/TR)
unnamed: R402.1, R403.1, U401.7 (FB/VSET)
unnamed: C402.1, U401.5 (SS/TR)
unnamed: R102.2, VR101.2 (WIPER), VR101.3 (CW)
unnamed: R202.2, VR201.2 (WIPER), VR201.3 (CW)
unnamed: R302.2, VR301.2 (WIPER), VR301.3 (CW)
unnamed: R402.2, VR401.2 (WIPER), VR401.3 (CW)

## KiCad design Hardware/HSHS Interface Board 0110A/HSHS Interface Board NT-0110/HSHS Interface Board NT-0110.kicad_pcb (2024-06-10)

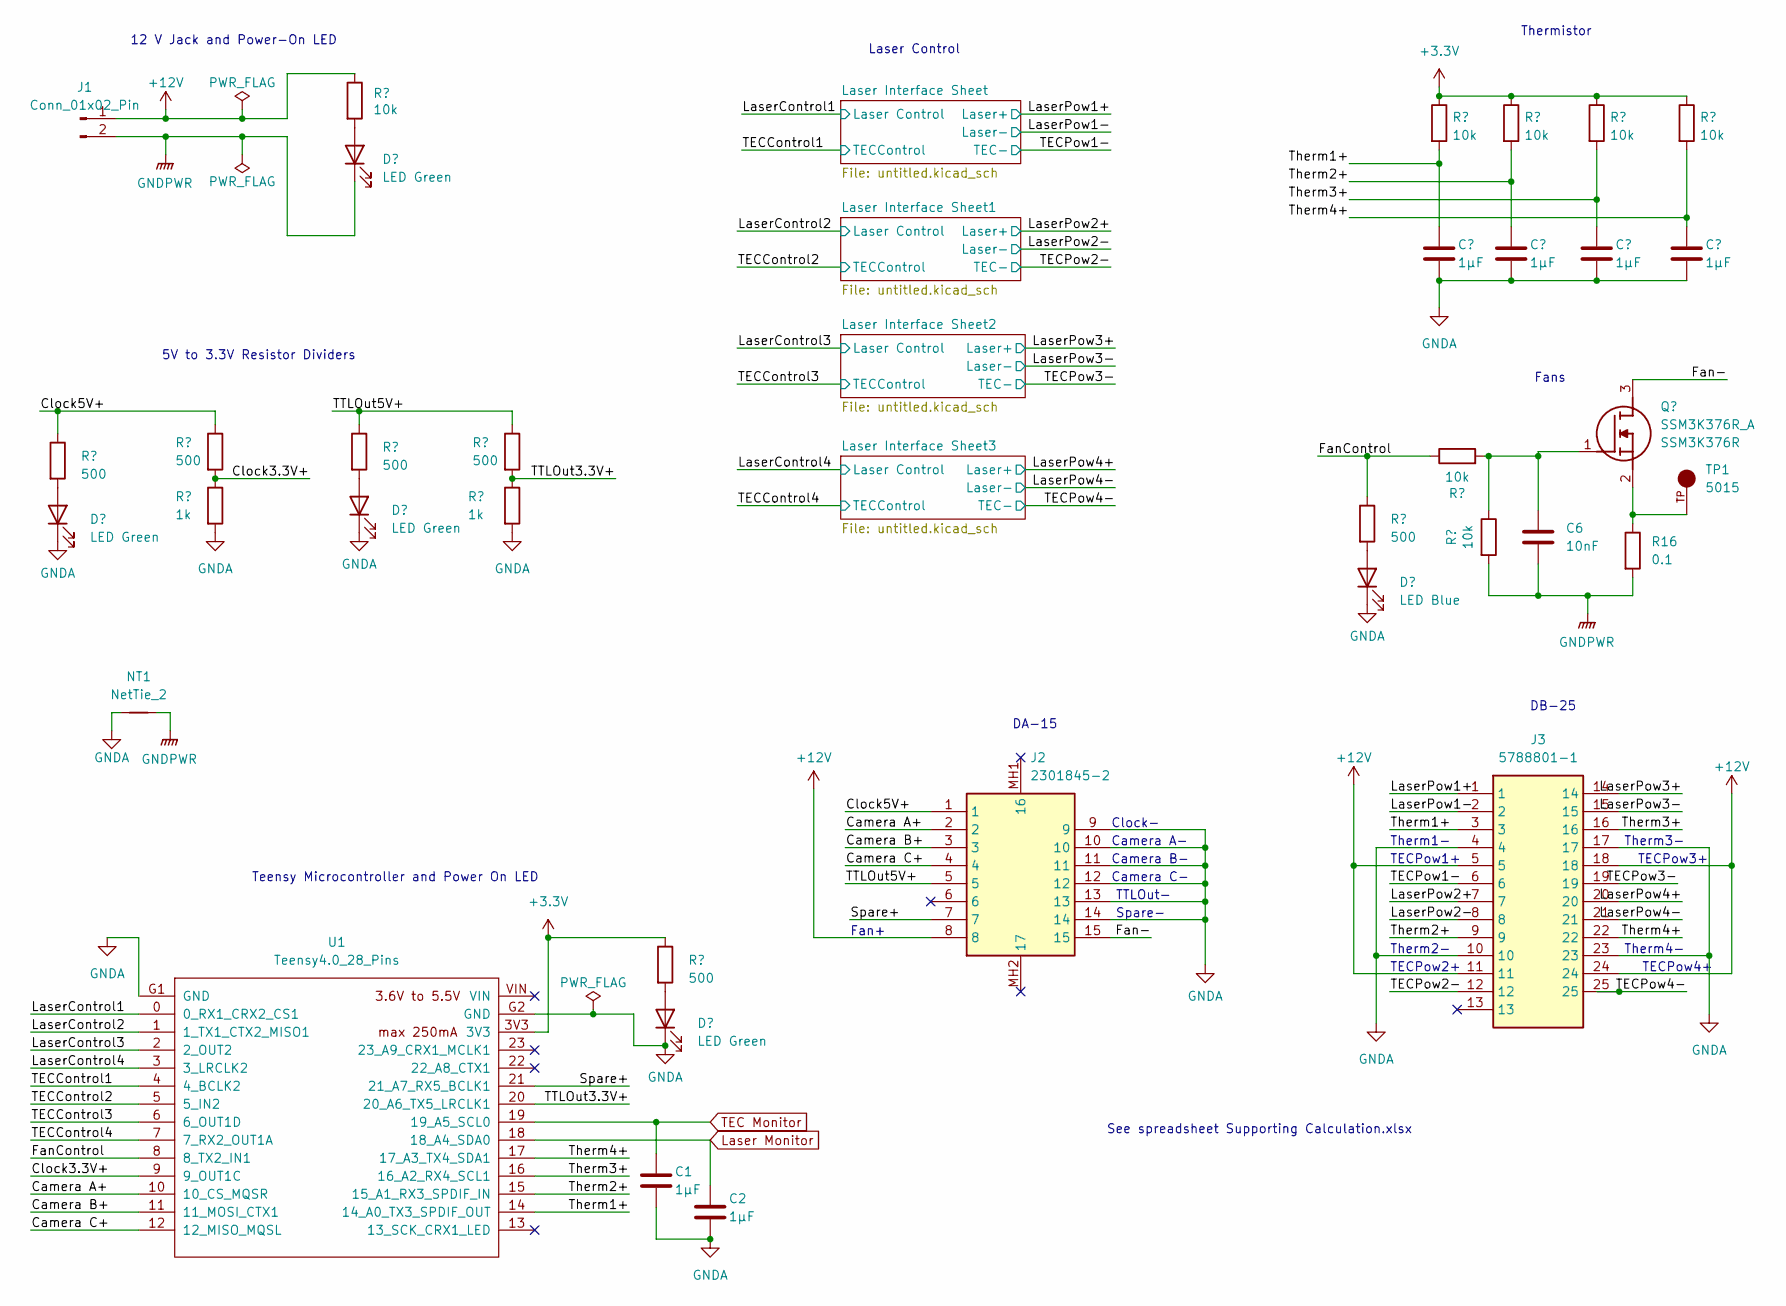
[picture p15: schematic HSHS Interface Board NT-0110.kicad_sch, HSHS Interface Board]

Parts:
C1, C2: 1µF; C_0603_1608Metric; Manufacturer Part Number CL10A105KA8NNNC; Digikey_Part_Number 1276-1102-1-ND
C3, C4, C5, C7: 1µF; C_0603_1608Metric; Manufacturer_Part_Number CL10A105KA8NNNC; Digikey_Part_Number 1276-1102-1-ND
C6: 10nF; C_0603_1608Metric; Manufacturer Part Number C0603C103K3RAC7867; Digikey_Part_Number 399-C0603C103K3RAC7867CT-ND
D1, D2, D3, D4: LED Green; D_0603_1608Metric; Manufacturer_Part_Number AA1608QBS/D-10MAV; Digikey_Part_Number 754-AA1608ZGSK-10MAVCT-ND
D5: LED Blue; D_0603_1608Metric; Manufacturer_Part_Number AA1608QBS/D-10MAV; Digikey_Part_Number 754-AA1608QBS/D-10MAVCT-ND
J1: Conn_01x02_Pin; Dual Solder Pads Both Sides No PTH
J2: 2301845-2; 23018452; Manufacturer_Part_Number 2301845-2; Mouser Part Number 571-2301845-2
J3: 5788801-1; 57888011; Manufacturer_Part_Number 5788801-1; Mouser Part Number 571-5788801-1
NT1: NetTie_2; NetTieSolderBridge
Q1: SSM3K376R_A; SSM3K376R_Mod_A; Manufacturer_Part_Number SSM3K376R,LF; Digikey_Part_Number SSM3K376RLFTR-ND
R1, R5: 500; R_0603_1608Metric; Manufacturer Part Number RC0603FR-10499RL; Digikey_Part_Number 13-RC0603FR-10499RLCT-ND
R2, R6: 1k; R_0603_1608Metric; Manufacturer Part Number RC0603FR-071KL; Digikey_Price/Stock https://www.digikey.com/en/products/det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
R3, R7, R8, R10: 500; R_0603_1608Metric; Manufacturer_Part_Number RC0603FR-10499RL; Digikey_Part_Number 13-RC0603FR-10499RLCT-ND
R4, R12, R13: 10k; R_0603_1608Metric; Manufacturer Part Number RMCF0603FT10K0; Digikey_Part_Number RMCF0603FT10K0CT-ND
R9, R11, R14, R15: 10k; R_0603_1608Metric; Manufacturer_Part_Number RNCP0603FTD10K0; Digikey_Part_Number RMCF0603FT10K0CT-ND
R16: 0.1; R_0805_2012Metric; Manufacturer Part Number RL1220S-R10-F; Digikey_Part_Number RL12S.10FCT-ND
TP1: 5015; KEYSTONE_5015; Manufacturer Part Number 5015; Digikey_Part_Number 36-5015CT-ND
U1: Teensy4.0_28_Pins; Teensy40_with_3D_Model_28_Pins_Surface_Mount_B; Manufacturer Part Number DEV-16997; Digikey_Part_Number 1568-DEV-16997-ND

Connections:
+3.3V: R8.1, R9.1, R11.1, R14.1, R15.1, U1.3V3
+12V: J1.1, J2.8, J3.5, J3.11, J3.18, J3.24, R4.1; also elsewhere on the board
/Camera A+: J2.2, U1.10 (10_CS_MQSR)
/Camera B+: J2.3, U1.11 (11_MOSI_CTX1)
/Camera C+: J2.4, U1.12 (12_MISO_MQSL)
/Clock3.3V+: R1.2, R2.1, U1.9 (9_OUT1C)
/Clock5V+: J2.1, R1.1, R3.1
/Fan-: J2.15, Q1.3 (D)
/FanControl: R10.1, R12.1, U1.8 (8_TX2_IN1)
/LaserControl3: U1.2 (2_OUT2); also elsewhere on the board
/LaserControl4: U1.3 (3_LRCLK2); also elsewhere on the board
/LaserPow1+: J3.1; also elsewhere on the board
/LaserPow1-: J3.2; also elsewhere on the board
/LaserPow2+: J3.7; also elsewhere on the board
/LaserPow2-: J3.8; also elsewhere on the board
/LaserPow3+: J3.14; also elsewhere on the board
/LaserPow3-: J3.15; also elsewhere on the board
/LaserPow4+: J3.20; also elsewhere on the board
/LaserPow4-: J3.21; also elsewhere on the board
/Spare+: J2.7, U1.21 (21_A7_RX5_BCLK1)
/TECControl3: U1.6 (6_OUT1D); also elsewhere on the board
/TECControl4: U1.7 (7_RX2_OUT1A); also elsewhere on the board
/TECPow1-: J3.6; also elsewhere on the board
/TECPow2-: J3.12; also elsewhere on the board
/TECPow3-: J3.19; also elsewhere on the board
/TECPow4-: J3.25; also elsewhere on the board
/TTLOut3.3V+: R5.2, R6.1, U1.20 (20_A6_TX5_LRCLK1)
/TTLOut5V+: J2.5, R5.1, R7.1
/Therm1+: C3.1, J3.3, R9.2, U1.14 (14_A0_TX3_SPDIF_OUT)
/Therm2+: C4.1, J3.9, R11.2, U1.15 (15_A1_RX3_SPDIF_IN)
/Therm3+: C5.1, J3.16, R14.2, U1.16 (16_A2_RX4_SCL1)
/Therm4+: C7.1, J3.22, R15.2, U1.17 (17_A3_TX4_SDA1)
GNDA: C1.2, C2.2, C3.2, C4.2, C5.2, C7.2, D1.1 (K), D3.1 (K), D4.1 (K), D5.1 (K), J2.9, J2.10, J2.11, J2.12, J2.13, J2.14, J3.4, J3.10, J3.17, J3.23, NT1.1, R2.2, R6.2, U1.G1 (GND), U1.G2 (GND); also elsewhere on the board
GNDPWR: C6.2, D2.1 (K), J1.2, NT1.2, R13.2, R16.2; also elsewhere on the board
Laser Monitor: C2.1, U1.18 (18_A4_SDA0); also elsewhere on the board
unnamed: D1.2 (A), R3.2
unnamed: D2.2 (A), R4.2
unnamed: D3.2 (A), R7.2
unnamed: D4.2 (A), R8.2
unnamed: D5.2 (A), R10.2
unnamed: C6.1, Q1.1 (G), R12.2, R13.1
unnamed: Q1.2 (S), R16.1, TP1.TP
TEC Monitor: C1.1, U1.19 (19_A5_SCL0); also elsewhere on the board

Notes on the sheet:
Camera A-
Therm3-
DA-15
Spare-
See spreadsheet Supporting Calculation.xlsx
DB-25
TECPow1+
Therm1-
TTLOut-
Therm4-
TECPow2+
5V to 3.3V Resistor Dividers
Fan+
Camera B-
Thermistor
Fans
Laser Control
TECPow3+
Camera C-
Teensy Microcontroller and Power On LED
12 V Jack and Power-On LED
Therm2-
TECPow4+
Clock-

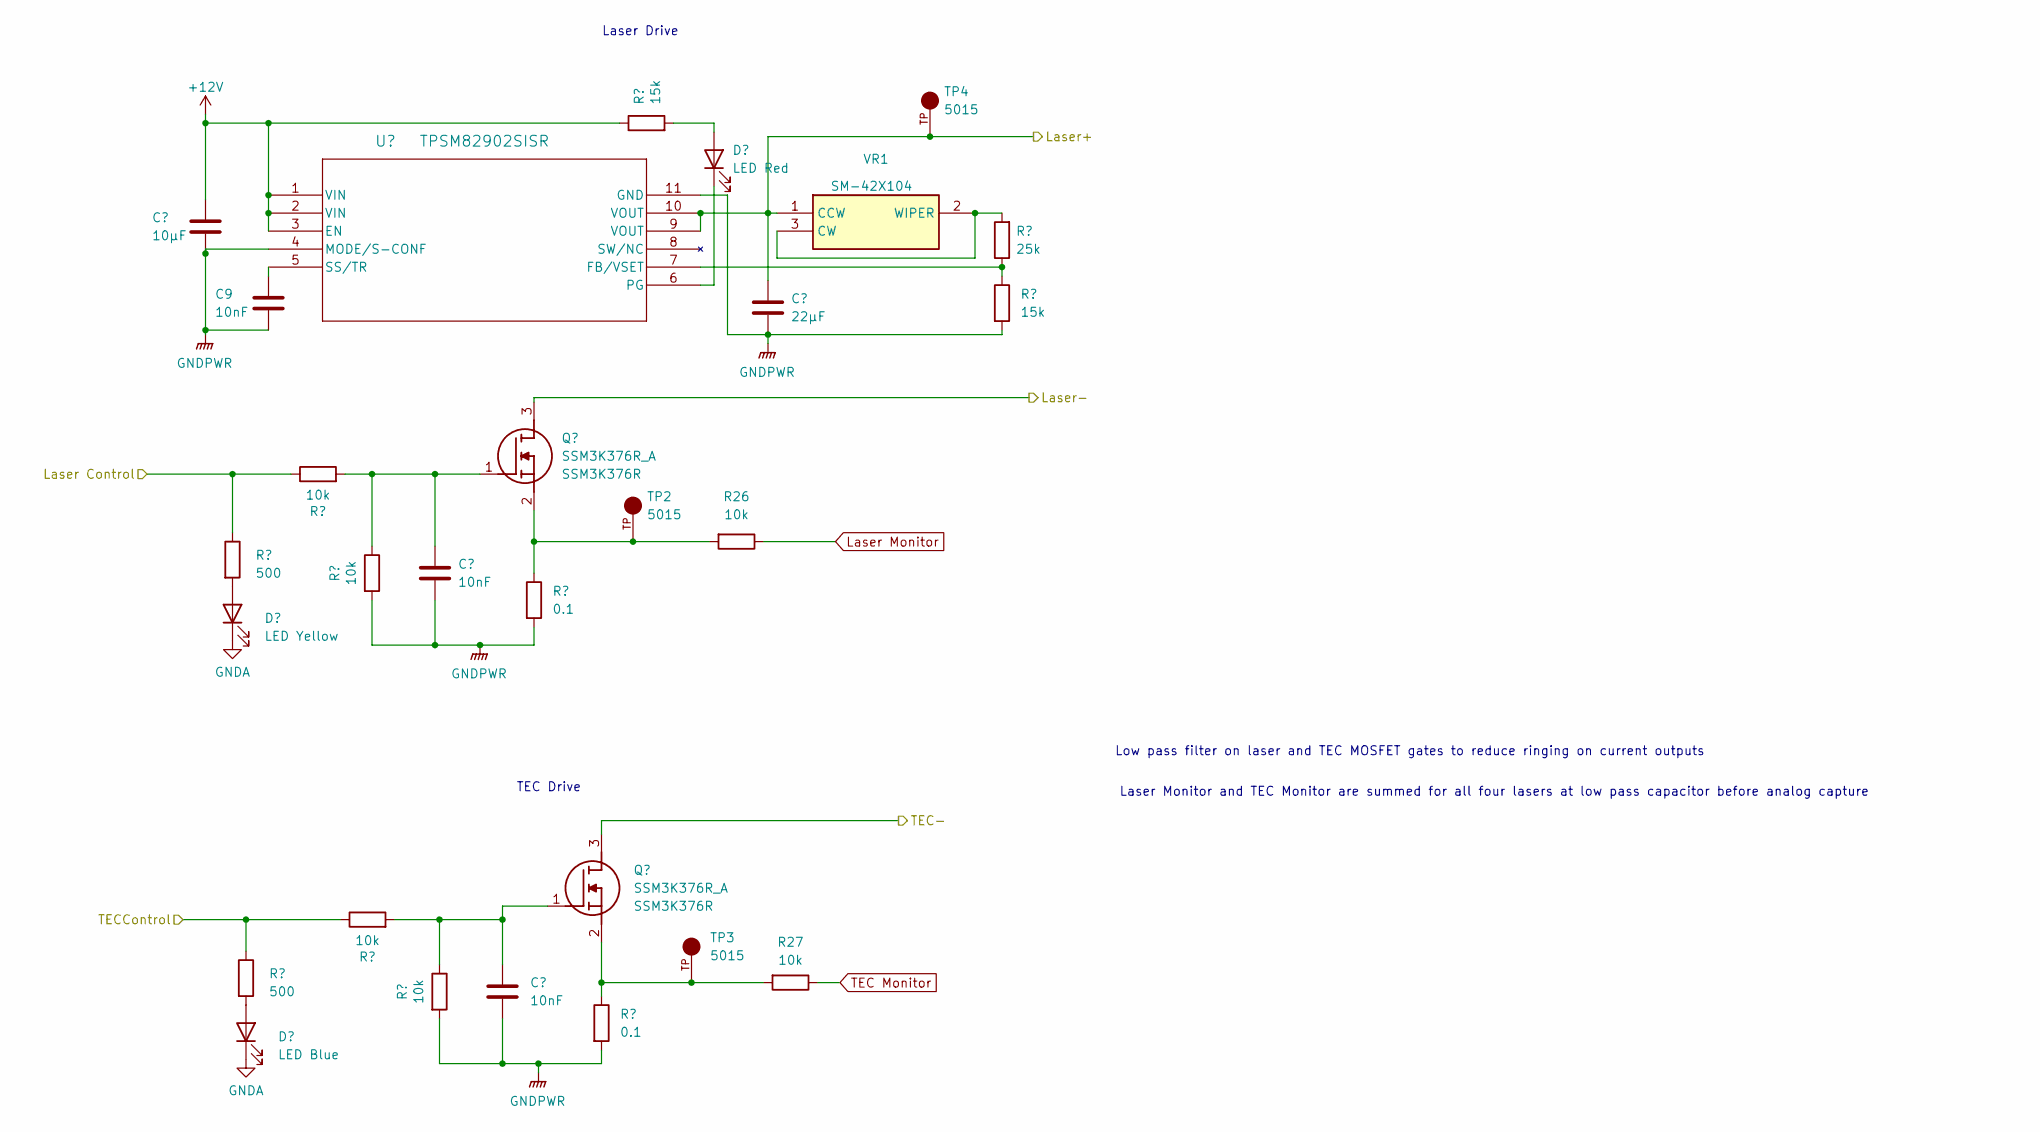
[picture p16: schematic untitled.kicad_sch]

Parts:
C8: 10µF; C_0805_2012Metric; Manufacturer Part Number CL21A106KOQNNNE; Digikey_Part_Number 1276-1096-1-ND
C9, C10, C11: 10nF; C_0603_1608Metric; Manufacturer Part Number C0603C103K3RAC7867; Digikey_Part_Number 399-C0603C103K3RAC7867CT-ND
C12: 22µF; C_0805_2012Metric; Manufacturer Part Number C2012X7S1A226M125AC; Digikey_Part_Number 445-14560-1-ND
D9: LED Yellow; D_0603_1608Metric; Manufacturer_Part_Number AA1608QBS/D-10MAV; Digikey_Part_Number 754-AA1608SYSKCT-ND
D10: LED Blue; D_0603_1608Metric; Manufacturer_Part_Number AA1608QBS/D-10MAV; Digikey_Part_Number 754-AA1608QBS/D-10MAVCT-ND
D11: LED Red; D_0603_1608Metric; Manufacturer_Part_Number AA1608QBS/D-10MAV; Digikey_Part_Number 754-AA1608SURSKCT-ND
Q2, Q3: SSM3K376R_A; SSM3K376R_Mod_A; Manufacturer_Part_Number SSM3K376R,LF; Digikey_Part_Number SSM3K376RLFTR-ND
R19, R20, R21, R22, R26, R27: 10k; R_0603_1608Metric; Manufacturer Part Number RMCF0603FT10K0; Digikey_Part_Number RMCF0603FT10K0CT-ND
R23, R24: 0.1; R_0805_2012Metric; Manufacturer Part Number RL1220S-R10-F; Digikey_Part_Number RL12S.10FCT-ND
R28: 25k; R_0603_1608Metric; Manufacturer Part Number ERJ-3EKF2492V; Digikey_Part_Number P24.9KHCT-ND
R29, R38: 15k; R_0603_1608Metric; Manufacturer Part Number RC0603FR-0715KL; Digikey_Part_Number 311-15.0KHRCT-ND
R30, R31: 500; R_0603_1608Metric; Manufacturer_Part_Number RC0603FR-10499RL; Digikey_Part_Number 13-RC0603FR-10499RLCT-ND
TP2, TP3, TP4: 5015; KEYSTONE_5015; Manufacturer Part Number 5015; Digikey_Part_Number 36-5015CT-ND
U2: TPSM82902SISR; uSIP11_SIS_TEX; Manufacturer Part Number TPSM82902SISR; Digikey_Part_Number 296-TPSM82902SISRCT-ND
VR1: SM-42X104; SM42X104; Manufacturer_Part_Number SM-42X104; Mouser Part Number 229-SM-42X104

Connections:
+12V: C8.1, R38.1, U2.1 (VIN), U2.2 (VIN), U2.3 (EN); also elsewhere on the board
/LaserPow1+: C12.1, TP4.TP, U2.9 (VOUT), U2.10 (VOUT), VR1.1 (CCW); also elsewhere on the board
/LaserPow1-: Q2.3 (D); also elsewhere on the board
/TECPow1-: Q3.3 (D); also elsewhere on the board
GNDA: D9.1 (K), D10.1 (K); also elsewhere on the board
GNDPWR: C8.2, C9.2, C10.2, C11.2, C12.2, R21.2, R22.2, R23.2, R24.2, R29.2, U2.4 (MODE/S-CONF), U2.11 (GND); also elsewhere on the board
Laser Monitor: R26.1; also elsewhere on the board
unnamed: D9.2 (A), R30.2
unnamed: D10.2 (A), R31.2
unnamed: D11.2 (A), R38.2
unnamed: C10.1, Q2.1 (G), R19.2, R21.1
unnamed: Q2.2 (S), R23.1, R26.2, TP2.TP
unnamed: C11.1, Q3.1 (G), R20.2, R22.1
unnamed: Q3.2 (S), R24.1, R27.2, TP3.TP
unnamed: R28.1, R29.1, U2.7 (FB/VSET)
unnamed: C9.1, U2.5 (SS/TR)
unnamed: R28.2, VR1.2 (WIPER), VR1.3 (CW)
TEC Monitor: R27.1; also elsewhere on the board

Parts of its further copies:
C13, C18, C23: 10µF; C_0805_2012Metric; Manufacturer Part Number CL21A106KOQNNNE; Digikey_Part_Number 1276-1096-1-ND
C14, C15, C16, C19, C20, C21, C24, C25, C26: 10nF; C_0603_1608Metric; Manufacturer Part Number C0603C103K3RAC7867; Digikey_Part_Number 399-C0603C103K3RAC7867CT-ND
C17, C22, C27: 22µF; C_0805_2012Metric; Manufacturer Part Number C2012X7S1A226M125AC; Digikey_Part_Number 445-14560-1-ND
D6, D12, D15: LED Yellow; D_0603_1608Metric; Manufacturer_Part_Number AA1608QBS/D-10MAV; Digikey_Part_Number 754-AA1608SYSKCT-ND
D7, D13, D16: LED Blue; D_0603_1608Metric; Manufacturer_Part_Number AA1608QBS/D-10MAV; Digikey_Part_Number 754-AA1608QBS/D-10MAVCT-ND
D8, D14, D17: LED Red; D_0603_1608Metric; Manufacturer_Part_Number AA1608QBS/D-10MAV; Digikey_Part_Number 754-AA1608SURSKCT-ND
Q4, Q5, Q6, Q7, Q8, Q9: SSM3K376R_A; SSM3K376R_Mod_A; Manufacturer_Part_Number SSM3K376R,LF; Digikey_Part_Number SSM3K376RLFTR-ND
R17, R18, R43, R44, R56, R57: 500; R_0603_1608Metric; Manufacturer_Part_Number RC0603FR-10499RL; Digikey_Part_Number 13-RC0603FR-10499RLCT-ND
R25, R42, R51, R55, R64, R68: 15k; R_0603_1608Metric; Manufacturer Part Number RC0603FR-0715KL; Digikey_Part_Number 311-15.0KHRCT-ND
R32, R33, R34, R35, R39, R40, R45, R46, R47, R48, R52, R53, R58, R59, R60, R61, R65, R66: 10k; R_0603_1608Metric; Manufacturer Part Number RMCF0603FT10K0; Digikey_Part_Number RMCF0603FT10K0CT-ND
R36, R37, R49, R50, R62, R63: 0.1; R_0805_2012Metric; Manufacturer Part Number RL1220S-R10-F; Digikey_Part_Number RL12S.10FCT-ND
R41, R54, R67: 25k; R_0603_1608Metric; Manufacturer Part Number ERJ-3EKF2492V; Digikey_Part_Number P24.9KHCT-ND
TP5, TP6, TP7, TP8, TP9, TP10, TP11, TP12, TP13: 5015; KEYSTONE_5015; Manufacturer Part Number 5015; Digikey_Part_Number 36-5015CT-ND
U3, U4, U5: TPSM82902SISR; uSIP11_SIS_TEX; Manufacturer Part Number TPSM82902SISR; Digikey_Part_Number 296-TPSM82902SISRCT-ND
VR2, VR3, VR4: SM-42X104; SM42X104; Manufacturer_Part_Number SM-42X104; Mouser Part Number 229-SM-42X104

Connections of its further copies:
+12V: C13.1, C18.1, C23.1, R25.1, R51.1, R64.1, U3.1 (VIN), U3.2 (VIN), U3.3 (EN), U4.1 (VIN), U4.2 (VIN), U4.3 (EN), U5.1 (VIN), U5.2 (VIN), U5.3 (EN); also elsewhere on the board
/LaserControl3: R43.1, R45.1; also elsewhere on the board
/LaserControl4: R56.1, R58.1; also elsewhere on the board
/LaserPow2+: C17.1, TP7.TP, U3.9 (VOUT), U3.10 (VOUT), VR2.1 (CCW); also elsewhere on the board
/LaserPow2-: Q4.3 (D); also elsewhere on the board
/LaserPow3+: C22.1, TP10.TP, U4.9 (VOUT), U4.10 (VOUT), VR3.1 (CCW); also elsewhere on the board
/LaserPow3-: Q6.3 (D); also elsewhere on the board
/LaserPow4+: C27.1, TP13.TP, U5.9 (VOUT), U5.10 (VOUT), VR4.1 (CCW); also elsewhere on the board
/LaserPow4-: Q8.3 (D); also elsewhere on the board
/TECControl3: R44.1, R46.1; also elsewhere on the board
/TECControl4: R57.1, R59.1; also elsewhere on the board
/TECPow2-: Q5.3 (D); also elsewhere on the board
/TECPow3-: Q7.3 (D); also elsewhere on the board
/TECPow4-: Q9.3 (D); also elsewhere on the board
GNDA: D6.1 (K), D7.1 (K), D12.1 (K), D13.1 (K), D15.1 (K), D16.1 (K); also elsewhere on the board
GNDPWR: C13.2, C14.2, C15.2, C16.2, C17.2, C18.2, C19.2, C20.2, C21.2, C22.2, C23.2, C24.2, C25.2, C26.2, C27.2, R34.2, R35.2, R36.2, R37.2, R42.2, R47.2, R48.2, R49.2, R50.2, R55.2, R60.2, R61.2, R62.2, R63.2, R68.2, U3.4 (MODE/S-CONF), U3.11 (GND), U4.4 (MODE/S-CONF), U4.11 (GND), U5.4 (MODE/S-CONF), U5.11 (GND); also elsewhere on the board
Laser Monitor: R39.1, R52.1, R65.1; also elsewhere on the board
unnamed: D6.2 (A), R17.2
unnamed: D7.2 (A), R18.2
unnamed: D8.2 (A), R25.2
unnamed: D12.2 (A), R43.2
unnamed: D13.2 (A), R44.2
unnamed: D14.2 (A), R51.2
unnamed: D14.1 (K), U4.6 (PG)
unnamed: D15.2 (A), R56.2
unnamed: D16.2 (A), R57.2
unnamed: D17.2 (A), R64.2
unnamed: D17.1 (K), U5.6 (PG)
unnamed: C15.1, Q4.1 (G), R32.2, R34.1
unnamed: Q4.2 (S), R36.1, R39.2, TP5.TP
unnamed: C16.1, Q5.1 (G), R33.2, R35.1
unnamed: Q5.2 (S), R37.1, R40.2, TP6.TP
unnamed: C20.1, Q6.1 (G), R45.2, R47.1
unnamed: Q6.2 (S), R49.1, R52.2, TP8.TP
unnamed: C21.1, Q7.1 (G), R46.2, R48.1
unnamed: Q7.2 (S), R50.1, R53.2, TP9.TP
unnamed: C25.1, Q8.1 (G), R58.2, R60.1
unnamed: Q8.2 (S), R62.1, R65.2, TP11.TP
unnamed: C26.1, Q9.1 (G), R59.2, R61.1
unnamed: Q9.2 (S), R63.1, R66.2, TP12.TP
unnamed: R41.1, R42.1, U3.7 (FB/VSET)
unnamed: C14.1, U3.5 (SS/TR)
unnamed: R54.1, R55.1, U4.7 (FB/VSET)
unnamed: C19.1, U4.5 (SS/TR)
unnamed: R67.1, R68.1, U5.7 (FB/VSET)
unnamed: C24.1, U5.5 (SS/TR)
unnamed: R41.2, VR2.2 (WIPER), VR2.3 (CW)
unnamed: R54.2, VR3.2 (WIPER), VR3.3 (CW)
unnamed: R67.2, VR4.2 (WIPER), VR4.3 (CW)
TEC Monitor: R40.1, R53.1, R66.1; also elsewhere on the board

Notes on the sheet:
TEC Drive
Laser Drive
Laser Monitor and TEC Monitor are summed for all four lasers at low pass capacitor before analog capture
Low pass filter on laser and TEC MOSFET gates to reduce ringing on current outputs

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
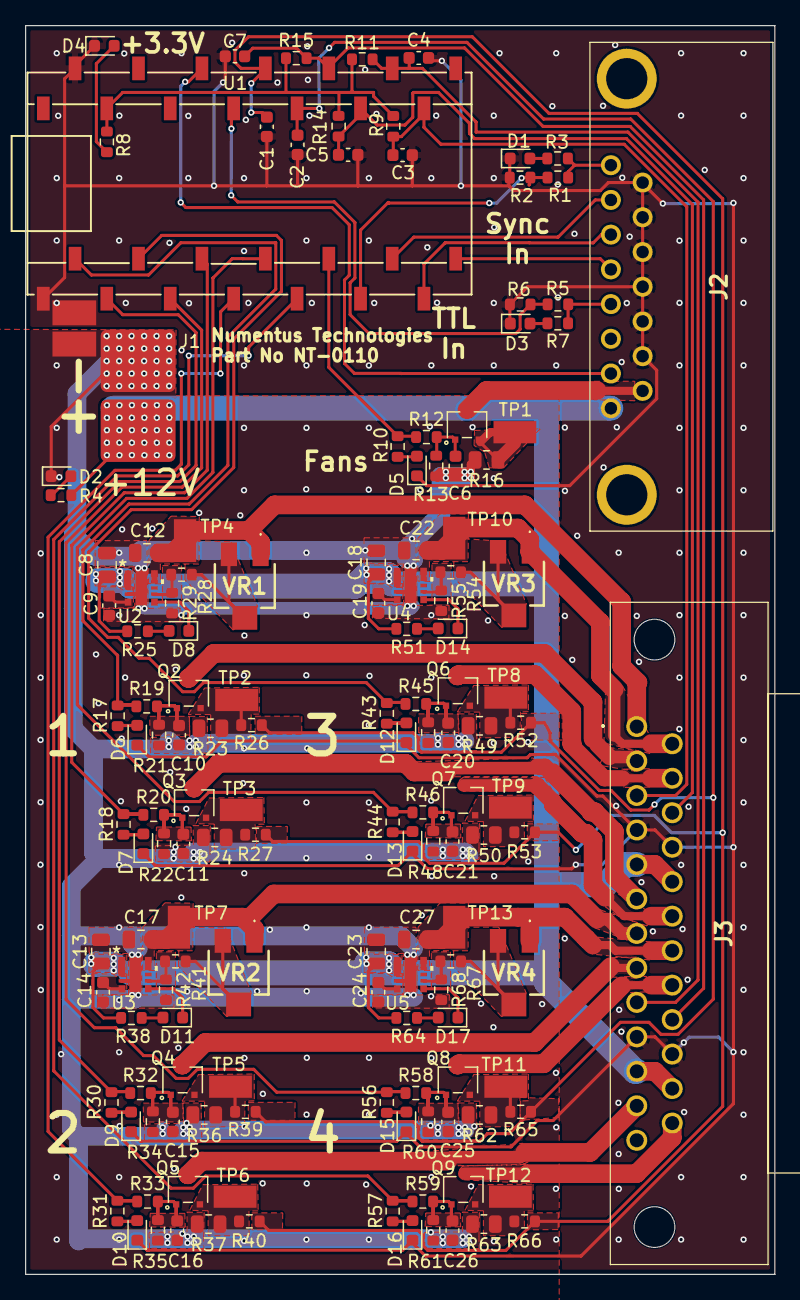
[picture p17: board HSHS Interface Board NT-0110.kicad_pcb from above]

Board: 2 copper layers, 60.0 x 100.0 mm, 147 parts (0 on the bottom side), 91 nets.

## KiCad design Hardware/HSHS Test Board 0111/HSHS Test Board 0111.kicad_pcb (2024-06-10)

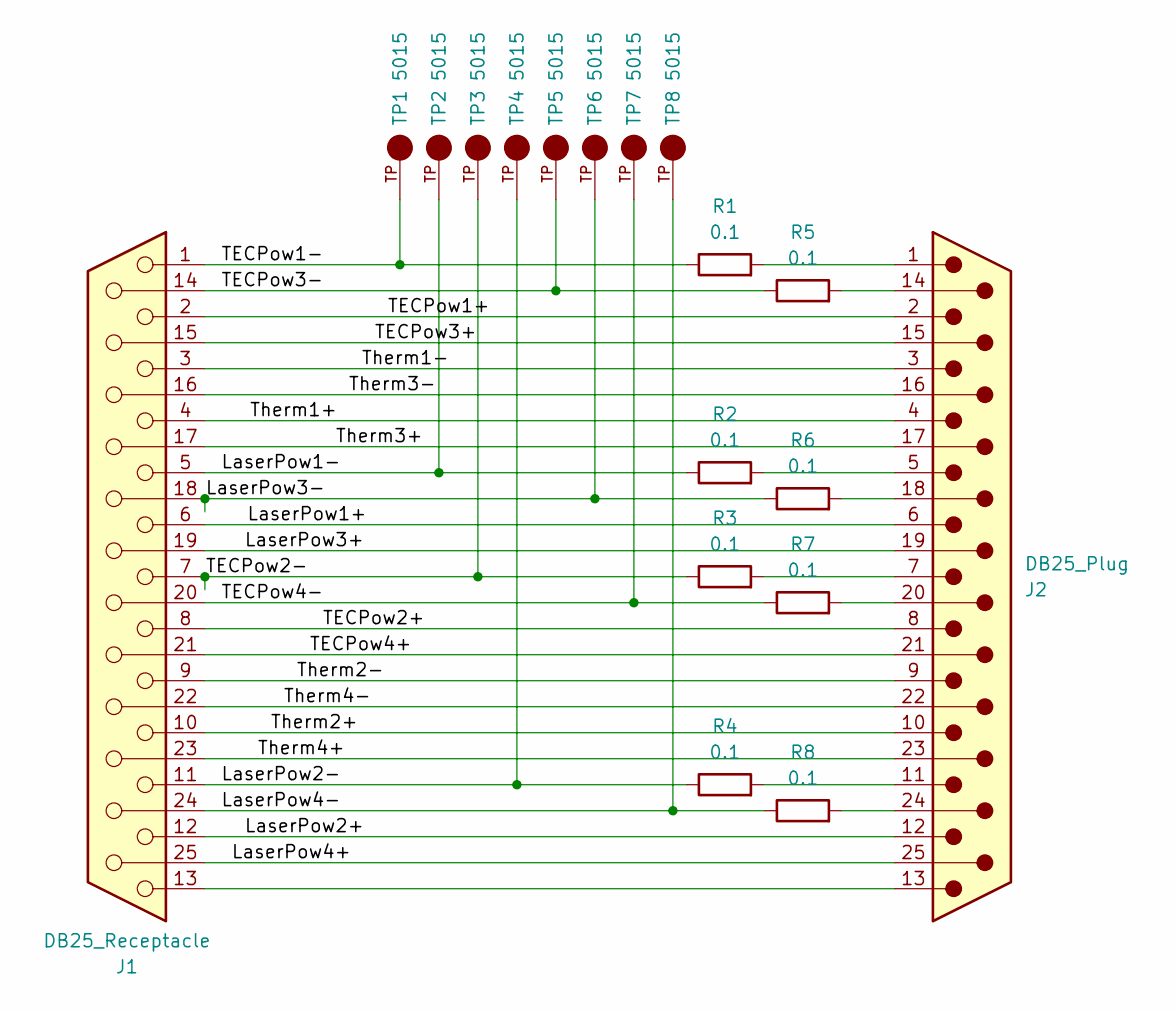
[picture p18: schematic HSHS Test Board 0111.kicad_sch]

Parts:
J1: DB25_Receptacle; 57888011_A; Manufacturer Part Number 5788801-1; Digikey_Part_Number A35139-ND
J2: DB25_Plug; 5788794_1 Mod From 57888011_A; Manufacturer Part Number 5788794-1; Digikey_Part_Number A35132-ND
R1, R2, R3, R4, R5, R6, R7, R8: 0.1; R_0805_2012Metric
TP1, TP2, TP3, TP4, TP5, TP6, TP7, TP8: 5015; KEYSTONE_5015; Manufacturer Part Number 5015; Digikey_Part_Number 36-5015CT-ND

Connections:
/LaserPow1+: J1.6, J2.6
/LaserPow1-: J1.5, R2.1, TP2.TP
/LaserPow2+: J1.12, J2.12
/LaserPow2-: J1.11, R4.1, TP4.TP
/LaserPow3+: J1.19, J2.19
/LaserPow3-: J1.18, R6.1, TP6.TP
/LaserPow4+: J1.25, J2.25
/LaserPow4-: J1.24, R8.1, TP8.TP
/TECPow1+: J1.2, J2.2
/TECPow1-: J1.1, R1.1, TP1.TP
/TECPow2+: J1.8, J2.8
/TECPow2-: J1.7, R3.1, TP3.TP
/TECPow3+: J1.15, J2.15
/TECPow3-: J1.14, R5.1, TP5.TP
/TECPow4+: J1.21, J2.21
/TECPow4-: J1.20, R7.1, TP7.TP
/Therm1+: J1.4, J2.4
/Therm1-: J1.3, J2.3
/Therm2+: J1.10, J2.10
/Therm2-: J1.9, J2.9
/Therm3+: J1.17, J2.17
/Therm3-: J1.16, J2.16
/Therm4+: J1.23, J2.23
/Therm4-: J1.22, J2.22
unnamed: J1.13, J2.13
unnamed: J2.14, R5.2
unnamed: J2.18, R6.2
unnamed: J2.20, R7.2
unnamed: J2.24, R8.2
unnamed: J2.1, R1.2
unnamed: J2.5, R2.2
unnamed: J2.7, R3.2
unnamed: J2.11, R4.2

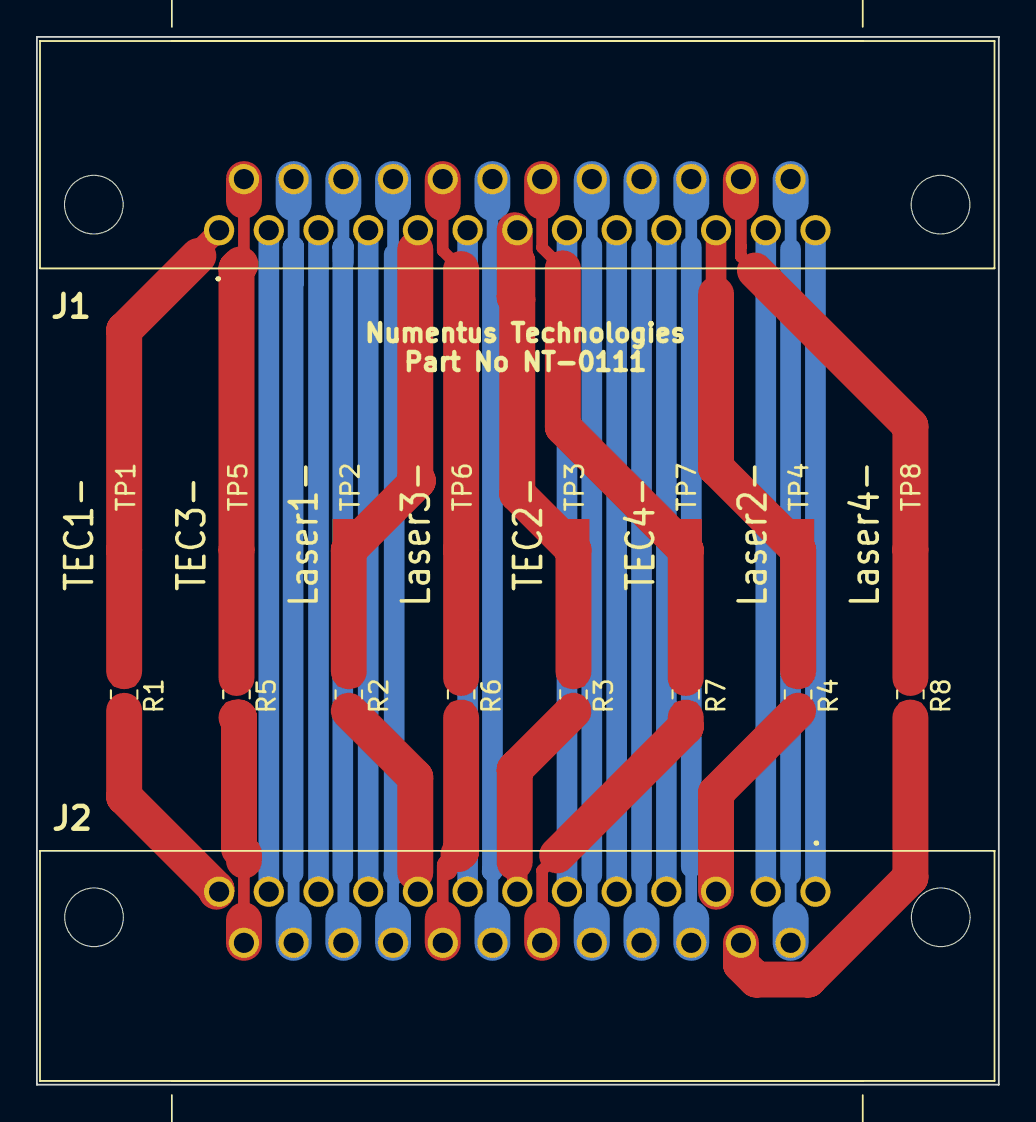
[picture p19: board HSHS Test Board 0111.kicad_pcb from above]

Board: 2 copper layers, 53.4 x 58.2 mm, 18 parts (0 on the bottom side), 33 nets.

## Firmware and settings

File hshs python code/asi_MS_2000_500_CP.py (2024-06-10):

import serial

class Controller:
    '''
    Basic device adaptor for ASI MS-2000-500-CP multi-axis stage controller.
    See 'ASI_controller_labels.pdf' for explanation of model name. Many more
    commands are available and have not been implemented.
    '''
    def __init__(self,
                 which_port,                # COM port for controller
                 axes=None,                 # ('X','Y'), ('Z',), ('X','Y','Z')
                 lead_screws=None,          # 'UC', 'SC', 'S', 'F', 'XF' (tuple)
                 axes_min_mm=None,          # min range (tuple)
                 axes_max_mm=None,          # max range (tuple)
                 encoder_counts_per_um=None,# optional -> expert only (tuple)
                 use_pwm=False,             # optional pwm output for LED
                 name='MS-2000-500-CP',     # optional name
                 verbose=True,              # False for max speed
                 very_verbose=False):       # True for debug
        self.name = name
        self.verbose = verbose
        self.very_verbose = very_verbose
        which_port = "COM5"
        if self.verbose: print('%s: Opening...'%name, end='')
        try:
            self.port = serial.Serial(
                port=which_port, baudrate=115200, timeout=5)
        except serial.serialutil.SerialException:
            raise IOError('%s: No connection on port %s'%(name, which_port))
        if self.verbose: print(" done.")
        self.version = self._send('V').strip(':A \r\n')
        print(f"self.version: {self.version}")
        assert self.version == 'Version: USB-9.2k', (
            '%s: controller version not supported'%name)
        self._set_ttl_in_mode('disabled')
        self._set_ttl_out_mode('low')
        self.state = None
        if axes is not None:
            assert axes == ('X','Y') or axes == ('Z',) or axes == ('X','Y','Z')
            self.axes = axes
            assert lead_screws is not None, 'please choose lead screw options'
            assert len(lead_screws) == len(axes)
            screw2value = { # pitch (mm), res (nm), speed (mm/s)
                'UC':(25.40, 88.0, 28.0),   # 'ultra-course'
                'SC':(12.70, 44.0, 14.0),   # 'super-course'
                'S' :(6.350, 22.0, 7.00),   # 'standard'
                'F' :(1.590, 5.50, 1.75),   # 'fine'
                'XF':(0.653, 2.20, 0.70)}   # 'extra-fine'
            pitch_mm, resolution_nm, max_velocity_mmps = [], [], []
            for a in range(len(axes)):
                pitch_mm.append(screw2value[lead_screws[a]][0])
                resolution_nm.append(screw2value[lead_screws[a]][1])
                max_velocity_mmps.append(screw2value[lead_screws[a]][2])
            self.pitch_mm = tuple(pitch_mm)
            self.resolution_nm = tuple(resolution_nm)
            self.max_velocity_mmps = tuple(max_velocity_mmps)
            assert axes_min_mm is not None, 'please specify min range of axes'
            assert axes_max_mm is not None, 'please specify max range of axes'
            assert len(axes_min_mm) == len(axes)
            assert len(axes_max_mm) == len(axes)
            for v in axes_min_mm: assert type(v) is int or type(v) is float
            for v in axes_max_mm: assert type(v) is int or type(v) is float
            self.min_position_um = tuple(1e3 * v for v in axes_min_mm)
            self.max_position_um = tuple(1e3 * v for v in axes_max_mm)
            self.encoder_counts_per_um = len(axes)*(10,)# default value
            if encoder_counts_per_um is not None:
                assert len(encoder_counts_per_um) == len(axes)
                for v in encoder_counts_per_um: assert type(v) is int
                self.encoder_counts_per_um = encoder_counts_per_um
            self.min_acceleration_ms = len(axes)*(25,)  # min acc/dec ramp
            self.max_acceleration_ms = len(axes)*(1e3,) # max acc/dec ramp
            self.max_settle_time_ms = len(axes)*(1e3,)  # max pause after move
            self.tol_settle_time_ms = len(axes)*(1,)    # tolerance
            self.min_precision_um = len(axes)*(1,)      # high precision limit
            self.max_precision_um = len(axes)*(1e6,)    # low precision limit
            self._set_velocity(tuple(0.67 * v for v in self.max_velocity_mmps))
            self._set_acceleration(self.min_acceleration_ms)
            self._set_settle_time(len(axes)*(0,))
            self._set_precision(self.min_precision_um)
            self._get_position()
            self._moving = False
        if use_pwm:
            self.set_pwm_state('off')
            self.set_pwm_intensity(1)
        return None

    def _send(self, cmd, respond=True, parse_axes=False):
        if self.very_verbose:
            print("%s: sending cmd = "%self.name, cmd)
        assert type(cmd) is str, 'command should be a string'
        cmd = bytes(cmd, encoding='ascii')
        self.port.write(cmd + b'\r')
        response = self.port.readline().decode('ascii').strip(':A \r\n')
        if respond:
            assert response != '', '%s: No response'%self.name
            if parse_axes:
                axes, values = [], []
                for a in response.split():
                    axis, value = a.split('=')
                    axes.append(axis), values.append(float(value))
                assert tuple(axes) == self.axes
                response = tuple(values)
        else:
            response = None
        if self.very_verbose:
            print("%s: -> response = "%self.name, response)
        assert self.port.in_waiting == 0
        return response

    def _get_ttl_in_mode(self):
        if self.verbose:
            print("%s: getting ttl in mode"%self.name)
        code2mode = {'0': 'disabled', '10': 'toggle_ttl_out'}
        code = self._send('TTL X?').rstrip().split('=')[1]
        self._ttl_in_mode = code2mode[code]
        if self.verbose:
            print("%s: -> ttl in mode = %s"%(self.name, self._ttl_in_mode))
        return self._ttl_in_mode

    def _set_ttl_in_mode(self, mode):
        if self.verbose:
            print("%s: setting ttl in mode = %s"%(self.name, mode))
        mode2code = {'disabled':'0', 'toggle_ttl_out':'10'}
        assert mode in mode2code, "mode '%s' not allowed"%mode
        self._ttl_in_mode = self._send(
            'TTL X=%s'%mode2code[mode], respond=False)
        assert self._get_ttl_in_mode() == mode
        if self.verbose:
            print("%s: -> done setting ttl in mode."%self.name)
        return None

    def _get_ttl_out_mode(self):
        if self.verbose:
            print("%s: getting ttl out mode"%self.name)
        code2mode = {'0': 'low', '1': 'high', '9': 'pwm'}
        code = self._send('TTL Y?').rstrip().split('=')[1]
        self._ttl_out_mode = code2mode[code]
        if self.verbose:
            print("%s: -> ttl out mode = %s"%(self.name, self._ttl_out_mode))
        return self._ttl_out_mode

    def _set_ttl_out_mode(self, mode):
        if self.verbose:
            print("%s: setting ttl out mode = %s"%(self.name, mode))
        mode2code = {'low':'0', 'high':'1', 'pwm':'9'}
        assert mode in mode2code, "mode '%s' not allowed"%mode
        self._ttl_out_mode = self._send(
            'TTL Y=%s'%mode2code[mode], respond=False)
        assert self._get_ttl_out_mode() == mode
        if self.verbose:
            print("%s: -> done setting ttl out mode."%self.name)
        return None

    def _get_velocity(self):
        if self.verbose:
            print("%s: getting velocity"%self.name)
        self.velocity_mmps = self._send(
            'S '+'? '.join(self.axes)+'?', parse_axes=True)
        if self.verbose:
            print("%s: -> velocity (mm/s) = %s"%(self.name, self.velocity_mmps))
        return self.velocity_mmps

    def _set_velocity(self, velocity_mmps): # tuple i.e. (2, 5, None)
        if self.verbose:
            print("%s: setting velocity = %s"%(self.name, velocity_mmps))
        assert len(velocity_mmps) == len(self.axes)
        for v in velocity_mmps: assert type(v) is int or type(v) is float
        cmd_string = ['S ']
        velocity_mmps = list(velocity_mmps)
        for i, v in enumerate(velocity_mmps):
            if v is None:
                velocity_mmps[i] = self.velocity_mmps[i]
            assert 0 <= velocity_mmps[i] <= self.max_velocity_mmps[i]
            velocity_mmps[i] = round(velocity_mmps[i], 6)
            cmd_string.append('V%s=%0.6f '%(self.axes[i], velocity_mmps[i]))
        self._send(''.join(cmd_string), respond=False)
        assert self._get_velocity() == tuple(velocity_mmps)
        if self.verbose:
            print("%s: -> done setting velocity."%self.name)
        return None

    def _get_acceleration(self): # acceleration or deceleration ramp time (ms)
        if self.verbose:
            print("%s: getting acceleration"%self.name)
        self.acceleration_ms = self._send(
            'AC '+'? '.join(self.axes)+'?', parse_axes=True)
        if self.verbose:
            print("%s: -> acceleration (ms) = %s"%(
                self.name, self.acceleration_ms))
        return self.acceleration_ms

    def _set_acceleration(self, acceleration_ms): # tuple i.e. (2, 5, None)
        if self.verbose:
            print("%s: setting acceleration = %s"%(self.name, acceleration_ms))
        assert len(acceleration_ms) == len(self.axes)
        for v in acceleration_ms: assert type(v) is int or type(v) is float
        cmd_string = ['AC ']
        acceleration_ms = list(acceleration_ms)
        for i, a in enumerate(acceleration_ms):
            if a is None:
                acceleration_ms[i] = self.acceleration_ms[i]
            acceleration_ms[i] = round(acceleration_ms[i])
            assert acceleration_ms[i] >= self.min_acceleration_ms[i]
            assert acceleration_ms[i] <= self.max_acceleration_ms[i]
            cmd_string.append('AC%s=%0.6f '%(self.axes[i], acceleration_ms[i]))
        self._send(''.join(cmd_string), respond=False)
        assert self._get_acceleration() == tuple(acceleration_ms)
        if self.verbose:
            print("%s: -> done setting acceleration."%self.name)
        return None

    def _get_settle_time(self): # time spent at end of move (ms)
        if self.verbose:
            print("%s: getting settle time"%self.name)
        self.settle_time_ms = self._send(
            'WT '+'? '.join(self.axes)+'?', parse_axes=True)
        if self.verbose:
            print("%s: -> settle time (ms) = %s"%(
                self.name, self.settle_time_ms))
        return self.settle_time_ms

    def _set_settle_time(self, settle_time_ms): # tuple i.e. (2, 5, None)
        if self.verbose:
            print("%s: setting settle time = %s"%(self.name, settle_time_ms))
        assert len(settle_time_ms) == len(self.axes)
        for v in settle_time_ms: assert type(v) is int or type(v) is float
        cmd_string = ['WT ']
        settle_time_ms = list(settle_time_ms)
        for i, t in enumerate(settle_time_ms):
            if t is None:
                settle_time_ms[i] = self.settle_time_ms[i]
            settle_time_ms[i] = round(settle_time_ms[i])
            assert 0 <= settle_time_ms[i] <= self.max_settle_time_ms[i]
            cmd_string.append('WT%s=%0.6f '%(self.axes[i], settle_time_ms[i]))
        self._send(''.join(cmd_string), respond=False)
        self._get_settle_time()
        for i, (ti, tf) in enumerate(zip(settle_time_ms, self.settle_time_ms)):
            assert tf >= ti - self.tol_settle_time_ms[i]
            assert tf <= ti + self.tol_settle_time_ms[i]
        if self.verbose:
            print("%s: -> done setting settle_time."%self.name)
        return None

    def _get_precision(self): # acceptable error between target and actual (um)
        if self.verbose:
            print("%s: getting precision"%self.name)
        precision_mm = self._send(
            'PC '+'? '.join(self.axes)+'?', parse_axes=True)
        self.precision_um = tuple(round(1e6 * p) for p in precision_mm)
        if self.verbose:
            print("%s: -> precision (um) = %s"%(
                self.name, self.precision_um))
        return self.precision_um

    def _set_precision(self, precision_um): # tuple i.e. (2, 5, None)
        if self.verbose:
            print("%s: setting precision = %s"%(self.name, precision_um))
        assert len(precision_um) == len(self.axes)
        for v in precision_um: assert type(v) is int or type(v) is float
        cmd_string = ['PC ']
        precision_um = list(precision_um)
        for i, p in enumerate(precision_um):
            if p is None:
                precision_um[i] = self.precision_um[i]
            precision_um[i] = round(precision_um[i])
            assert precision_um[i] >= self.min_precision_um[i]
            assert precision_um[i] <= self.max_precision_um[i]
            cmd_string.append(
                'PC%s=%0.6f '%(self.axes[i], 1e-6 * precision_um[i]))
        self._send(''.join(cmd_string), respond=False)
        assert self._get_precision() == tuple(precision_um)
        if self.verbose:
            print("%s: -> done setting precision."%self.name)
        return None

    def _counts2position(self, counts):
        position_um = []
        for count, factor in zip(counts, self.encoder_counts_per_um):
            position_um.append(float(count) / factor)
        return tuple(position_um)

    def _position2counts(self, position_um):
        counts = []
        for position, factor in zip(position_um, self.encoder_counts_per_um):
            counts.append(round(position * factor))
        return tuple(counts)

    def _get_position(self):
        if self.verbose:
            print("%s: getting position"%self.name)
        response = self._send('W '+' '.join(self.axes)).strip(':A \r\n').split()
        self.position_um = self._counts2position(response)
        if self.verbose:
            print("%s: -> position (um) = %s"%(self.name, self.position_um))
        return self.position_um

    def _finish_moving(self):
        if not self._moving:
            return None
        while True:
            status = self._send('/')
            if status == 'N':
                break
        self._get_position()
        for i, p in enumerate(self.position_um):
            assert p >= self._target_move_um[i] - self.precision_um[i]
            assert p <= self._target_move_um[i] + self.precision_um[i]
        self._moving = False
        if self.verbose: print('%s: -> finished moving'%self.name)
        return None

    def move_um(self, move_um, relative=True, block=True):
        self._finish_moving()
        assert len(move_um) == len(self.axes)
        for v in move_um: assert type(v) is int or type(v) is float or v is None
        move_um = list(move_um)
        for i, m in enumerate(move_um):
            if m is None:
                move_um[i] = self.position_um[i]
            if m is not None and relative:
                move_um[i] = self.position_um[i] + move_um[i]
            assert move_um[i] >= self.min_position_um[i]
            assert move_um[i] <= self.max_position_um[i]
        move_um = tuple(round(v, 3) for v in move_um) # round to nm
        if self.verbose:
            print("%s: moving to (um) = %s"%(self.name, move_um))
        cmd_string = ['M ']
        for i in range(len(self.axes)):
            cmd_string.append('%s=%0.6f '%(self.axes[i],
                                           self._position2counts(move_um)[i]))
        self._send(''.join(cmd_string), respond=False)
        self._moving = True
        self._target_move_um = move_um
        if block:
            self._finish_moving()
        return None

    def get_pwm_intensity(self):
        if self.verbose:
            print("%s: getting pwm intensity"%self.name)
        response = self._send('LED X?') # non-standard answer: 'X=val :A'
        self.pwm_intensity = int(response.split('=')[1])
        if self.verbose:
            print("%s: -> pwm intensity (%%) = %s"%(
                self.name, self.pwm_intensity))
        return self.pwm_intensity

    def set_pwm_intensity(self, intensity):
        if self.verbose:
            print("%s: setting pwm intensity = %s"%(self.name, intensity))
        assert type(intensity) is int or type(intensity) is float
        intensity = int(intensity)
        assert 1 <= intensity <= 99
        self._send('LED X=%d'%intensity, respond=False)
        assert self.get_pwm_intensity() == intensity
        if self.verbose:
            print("%s: -> done setting pwm intensity."%self.name)
        return None

    def set_pwm_state(self, state):
        if self.verbose:
            print("%s: setting pwm state = %s"%(self.name, state))
        assert state in ('off', 'on', 'pwm', 'external')
        if state == 'off':
            self._set_ttl_in_mode('disabled')
            self._set_ttl_out_mode('low')
        if state == 'on':
            self._set_ttl_in_mode('disabled')
            self._set_ttl_out_mode('high')
        if state == 'pwm':
            self._set_ttl_in_mode('disabled')
            self._set_ttl_out_mode('pwm')
        if state == 'external':
            self._set_ttl_in_mode('toggle_ttl_out')
            self._set_ttl_out_mode('low')
        self.state = state
        if self.verbose:
            print("%s: -> done setting pwm state."%self.name)
        return None

    def close(self):
        if self.verbose: print("%s: closing..."%self.name)
        if self.state != 'off':
            self.set_pwm_state('off')
        self.port.close()
        if self.verbose: print("%s: closed."%self.name)
        return None

if __name__ == '__main__':
    port = 'COM3'
    # controller only:
    ms = Controller(which_port=port, verbose=True, very_verbose=True)
    ms.close()

    # controller + xy stage:
    ms = Controller(which_port=port,
                    axes=('X', 'Y'),
                    lead_screws=('S','S'),
                    axes_min_mm=(-50,-25),  # recommended to check and use!
                    axes_max_mm=( 50, 25),  # recommended to check and use!
                    )
    ms.move_um((0, 0), relative=False)      # home
    ms.close()

    # controller + z drive:
    ms = Controller(which_port=port,
                    axes=('Z',),
                    lead_screws=('F',),
                    axes_min_mm=(-10,),     # recommended to check and use!
                    axes_max_mm=( 10,),     # recommended to check and use!
                    )
    ms.move_um((0,), relative=False)        # home
    ms.close()

    # controller + pwm:
    ms = Controller(which_port=port, use_pwm=True)
    ms.set_pwm_state('on')
##    input('hit enter to continue')
    ms.close()

    # controller + xys stage + pwm:
    ms = Controller(which_port=port,
                    axes=('X', 'Y', 'Z'),
                    lead_screws=('S','S','F'),
                    axes_min_mm=(-50,-25,-10), # recommended to check and use!
                    axes_max_mm=( 50, 25, 10), # recommended to check and use!
                    use_pwm=True,
                    verbose=True,
                    very_verbose=False)
    # move stage:
    ms.move_um((0, 0, 0), relative=False)       # home
    for moves in range(3):
        ms.move_um((2000, 1000, None))          # relative moves
    ms.move_um((-1000, None, -50), block=False) # relative non-blocking
    print('do something else...')
    ms.move_um((0, 0, 0), relative=False)       # re-home (absolute)
    # use pwm:
    ms.set_pwm_state('on')
    ms.set_pwm_state('pwm')
    for intensity in range(1, 100, 10):
        ms.set_pwm_intensity(intensity)
    ms.set_pwm_state('external') # -> supply external pwm on ttl in
    ms.close()

    # random input testing:
    ms = Controller(which_port=port,
                    axes=('X', 'Y', 'Z'),
                    lead_screws=('S','S','F'),
                    axes_min_mm=(-50,-25,-10), # recommended to check and use!
                    axes_max_mm=( 50, 25, 10), # recommended to check and use!
                    use_pwm=True,
                    verbose=True,
                    very_verbose=False)

    from random import uniform as r
    iterations = 1 # tested to 10,000 without crash/fail
    min_vel = 1
    factor = 10
    min_pos = tuple(p / factor for p in ms.min_position_um)
    max_pos = tuple(p / factor for p in ms.max_position_um)
    for i in range(iterations):
        print('Test_A:',i)
        vel, acc, stl, pre, pos = [], [], [], [], []
        for a in range(len(ms.axes)):
            vel.append(r(min_vel, ms.max_velocity_mmps[a]))
            acc.append(r(ms.min_acceleration_ms[a], ms.max_acceleration_ms[a]))
            stl.append(r(0, ms.max_settle_time_ms[a]))
            pre.append(r(ms.min_precision_um[a], ms.max_precision_um[a]))
            pos.append(r(min_pos[a], max_pos[a]))
        ms._set_velocity(tuple(vel))
        ms._set_acceleration(tuple(acc))
        ms._set_settle_time(tuple(stl))
        ms._set_precision(tuple(pre))
        ms.move_um(tuple(pos), relative=False)

    ms._set_velocity(ms.max_velocity_mmps)          # max speed
    ms._set_acceleration(ms.min_acceleration_ms)    # fast acceration
    ms._set_settle_time(len(ms.axes)*(0,))          # no settle time
    ms._set_precision(ms.min_precision_um)          # max precision
    for i in range(iterations):
        print('Test_B:',i)
        pos = []
        for a in range(len(ms.axes)):
            pos.append(r(min_pos[a], max_pos[a]))
        ms.move_um(tuple(pos), relative=False)
    ms.move_um((0, 0, 0), relative=False)
    ms.close()

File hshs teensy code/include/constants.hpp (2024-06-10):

#ifndef __constants_hpp__
#define __constants_hpp__
#include <Arduino.h>

    enum errorType { NO_ERROR = 0, INVALID_COMMAND = -1, INVALID_ARGUMENT_COUNT = -2, INVALID_ARGUMENT_TYPE = -3, CANNOT_COMPLETE_COMMAND = -4, NOT_READY = -5};

namespace constants {

    static const uint16_t NUM_CHANNELS = 4;    // This is for sizing arrays
    static const float TEMPERATURE_CUTOUT = 50; //  Thermistor temperature that turns off laser and TEC
    static const float REFERENCE_RESISTANCE = 0.1;  //  Resistance for summed laser and summed tec monitor
    static const float HALL_SENSOR_VOLTS_PER_AMP = 0.264;    //  Response of ACS725LLCTR-10AU-S is 264 mV/A

    static const float DATA_UPDATE_INTERVAL_SEC = 0.01;
    static const uint16_t SAMPLES_TO_READ = DATA_UPDATE_INTERVAL_SEC / 0.0000405;    //  Approximately 40.5 microseconds for analog read of two photodiode channels
    static const float REPORT_INTERVAL_SEC = 0.2;
    static const uint16_t CYCLES_PER_DATA_POINT = REPORT_INTERVAL_SEC/DATA_UPDATE_INTERVAL_SEC;
    static const uint32_t CYCLES_FOR_ZERO_INIT = 3; //  Number of cycles with autofocus LED off before zero calibration
    static const uint32_t CYCLES_FOR_ZERO_CAL = 50; //  Number of cycles with autofocus LED off for zero calibration
    static const uint8_t PIN_IN_PD_1 = 14;      //  Pins to read photodiode voltages
    static const uint8_t PIN_IN_PD_2 = 15;
    static const uint8_t PIN_OUT_LED_LEVEL = 22;
    static const uint8_t PIN_OUT_SERVO_LEVEL = 23;
    static const float SERIAL_UPDATE_INTERVAL_SEC = 0.2;
    static const uint16_t SERIAL_TICK_INTERVAL = SERIAL_UPDATE_INTERVAL_SEC/DATA_UPDATE_INTERVAL_SEC;    //  
    static const double SERVO_MAX_VALUE = 1000;     //  Arbitrary maximum servo parameter to facilitate small changes in GUI (250 µm range means servo change of 0.1 is 0.025 µm)

    static const uint8_t RED_LED_PIN = 9;    //  3rd/Status LED
    static const uint8_t YELLOW_LED_PIN = 10;    //  3rd/Status LED
    static const uint8_t GREEN_LED_PIN = 11;    //  3rd/Status LED
    static const uint8_t BLUE_LED_PIN = 12;    //  3rd/Status LED
    static const uint8_t PIN_STATUS_LED = 13;    //  3rd/Status LED

    static const uint8_t CALC_START = 23; //Pin that goes high/low when calculations are complete to visualize timing on oscilloscope

//  Output pins
    static const uint8_t LASER_OUT_PIN_LIST[NUM_CHANNELS] = { 0, 1, 2, 3 };  // Laser power control pins
    static const uint8_t TEC_OUT_PIN_LIST[NUM_CHANNELS] = { 4, 5, 6, 7 };  // TEC power control pins
    static const uint8_t FAN_OUT_PIN = 8;  // fan control pin
    static const float LASER_OUT_FREQUENCY =  1000.0;      //  Slow frequency due to low pass filter on MOSFET gate
    static const float TEC_OUT_FREQUENCY =  1000.0;      //  Slow frequency due to low pass filter on MOSFET gate
    static const float FAN_OUT_FREQUENCY =  1000.0;      //  Slow frequency due to low pass filter on MOSFET gate


//  Input pins
    static const uint8_t CLOCK_DIN_PIN = 14;  // Clock/sync digital input pin
    static const uint8_t CAMERA_A_DIN_PIN = 10;  // Camera A digital input pin
    static const uint8_t CAMERA_B_DIN_PIN = 11;  // Camera B digital input pin
    static const uint8_t CAMERA_C_DIN_PIN = 12;  // Camera C digital input pin
    static const uint8_t THERMISTER_AIN_PIN_LIST[NUM_CHANNELS] = { 15, 16, 17, 18 };  // Thermistor analog input pins
    static const uint8_t LASER_CURRENT_AIN_PIN = 19;  // Summed laser current analog input pin
    static const uint8_t TEC_CURRENT_AIN_PIN = 20;  // Summed TEC current analog input pin
    static const uint8_t TTL_DIN_PIN = 9;  //  TTL digital input pin
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

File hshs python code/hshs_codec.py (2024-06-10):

"""Module for encoding and decoding data from MCU. Encoding is only for testing because encoding is normally handled by MCU"""
import copy
import numpy as np

NUM_CHANNELS = 4

class SerialFormatsNew:
    """Defines format elements for serial port data from MCU"""
    def __init__(self, value, n_bytes, offset, scaling):
        self.value = value
        self.n_bytes = n_bytes
        self.offset = offset
        self.scaling = scaling


class TextClass:
    """Defines sample for MCU text responses, which are not a fixed length"""
    def __init__(self):
        self.data_list = ['text']      #   This defines the order of data elements
        self.flag_code = 0xFD
        self.text =                 SerialFormatsNew(0, 1,  0, 1)
        self.size = None
class FitDataClass:
    """Defines sample for fit data package"""
    def __init__(self):
        self.data_list = ['transition_type', 'first_point', 'num_points', 'slopes', 'intercepts', 'debug_data', 'offset']      #   This defines the order of data elements
        self.flag_code = 0xFC
        self.type = 0   #   This is calculated from transition_type
        self.transition_type =      SerialFormatsNew(0,                     2,  0,          1)
        self.first_point =          SerialFormatsNew(0,                     4,  0,          1)
        self.num_points =           SerialFormatsNew(0,                     2,  0,          1)
        self.slopes =               SerialFormatsNew(0,   4,  110000000, 10000)    #   Array size is set here
        self.intercepts =           SerialFormatsNew(0,   4,  110000000, 10000)    #   Array size is set here
        self.debug_data =  SerialFormatsNew(0,   4,  0,          1000)    #   Array size is set here
        self.offset =               SerialFormatsNew(0,                     2,  0,          100)
        self.size = None

class HSHSDataClass:
    """Defines sample for crisp data package"""
    def __init__(self, num_channels):
        self.data_list = ['time', 'state_time', 'count', 'state_count', 'state', 'pd_1_value', 'pd_2_value', 'pd_diff_meas', 'pd_diff_set_point', \
                          'error_value', 'average_error', 'servo_value', 'crisp_led_value']      #   This defines the order of data elements
        self.flag_code = 0xFE
        self.time =                 SerialFormatsNew(0,                         4,  0,  1000)
        self.state_time =           SerialFormatsNew(0,                         4,  0,  1000)
        self.count =                SerialFormatsNew(0,                         4,  0,  1)
        self.state_count =          SerialFormatsNew(0,                         4,  0,  1)
        self.state =                SerialFormatsNew(0,                         2,  0,  1)
        self.pd_1_value =           SerialFormatsNew(0,                         2,  0,  10000)
        self.pd_2_value =           SerialFormatsNew(0,                         2,  0,  10000)
        self.pd_diff_meas =         SerialFormatsNew(0,                         4,  110000000,  100000)    #   Range -1000 to 1000
        self.pd_diff_set_point =    SerialFormatsNew(0,                         4,  110000000,  100000)    #   Range -1000 to 1000

        self.error_value =          SerialFormatsNew(0,                         4,  110000000,  50000)    #   Range -1000 to 1000
        self.average_error =         SerialFormatsNew(0,                         4,  110000000,  50000)    #   Range -1000 to 1000

        self.servo_value =          SerialFormatsNew(0,                         4,  0,  10000)  # Current range 0 to 1000
        self.crisp_led_value =      SerialFormatsNew(0,                         2,  0,  100)
        self.size = None

class HSHSDataClassNew:
    """Defines sample for crisp data package"""
    def __init__(self, num_channels):
        self.data_list = ['time', 'state_time', 'count', 'state_count', 'state', 'laser_pwm', 'tec_pwm', 'fan_pwm', 'laser_temperatures', 'temperature_set_points', \
                          'laser_current', 'tec_current']      #   This defines the order of data elements

        self.flag_code = 0xFE
        self.time =                 SerialFormatsNew(0,                         4,  0,  1000)
        self.state_time =           SerialFormatsNew(0,                         4,  0,  1000)
        self.count =                SerialFormatsNew(0,                         4,  0,  1)
        self.state_count =          SerialFormatsNew(0,                         4,  0,  1)
        self.state =                SerialFormatsNew(0,                         2,  0,  1)

        self.laser_pwm =            SerialFormatsNew(np.zeros(num_channels),    2,  0,  150)    #   Array size is set here
        self.tec_pwm =              SerialFormatsNew(np.zeros(num_channels),    2,  0,  150)    #   Array size is set here
        self.fan_pwm =              SerialFormatsNew(0,                         2,  0,  150)
        self.laser_temperatures =   SerialFormatsNew(np.zeros(num_channels),    2,  0,  150)    #   Array size is set here
        self.temperature_set_points =   SerialFormatsNew(np.zeros(num_channels),    2,  0,  150)    #   Array size is set here
        self.laser_current =        SerialFormatsNew(0,                         2,  0,  1500)
        self.tec_current =          SerialFormatsNew(0,                         2,  0,  1500)

        self.size = None
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
